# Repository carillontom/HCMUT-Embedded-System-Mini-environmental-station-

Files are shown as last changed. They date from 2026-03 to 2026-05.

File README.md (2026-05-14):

Group 8's project: Mini environmental station with STM32

Project Overview : Mini environmental monitoring station with module LCD display using I2C module and can alert with buzzer when certain conditions are met, sent data measured to phone UART app via Bluetooth with UART communication (module HC-05). The station use mcu stm32f103c8t6 aka blue pill that can measure real-time temperature & humidity (module DHT11), gas (module MQ2), and can display them on the lcd screen. The device also has 2 button, 1 to snooze the alarm, 1 to change the display mode in cycle.

Requirement definition: [https://docs.google.com/spreadsheets/d/1O582D53Wys3Cwzh6xRYdXv68gtSpY5OcIZm6p9dKSyE/edit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](https://docs.google.com/spreadsheets/d/1O582D53Wys3Cwzh6xRYdXv68gtSpY5OcIZm6p9dKSyE/edit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)

System specification: [https://docs.google.com/spreadsheets/d/1O582D53Wys3Cwzh6xRYdXv68gtSpY5OcIZm6p9dKSyE/edit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](https://docs.google.com/spreadsheets/d/1O582D53Wys3Cwzh6xRYdXv68gtSpY5OcIZm6p9dKSyE/edit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)

Block diagram: 
(In .pdf file)

Power tree:
(In .pdf file)

Schematic: 
(In .pdf file)

PCB Layout: 
(In .pdf file)

Full test: https://youtu.be/GwvQwB3FSAY
Gas test: https://youtu.be/L1KeKjgLLEk
Temp test: https://youtu.be/eYzAX3KRrvM

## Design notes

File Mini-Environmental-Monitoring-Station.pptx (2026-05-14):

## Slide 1

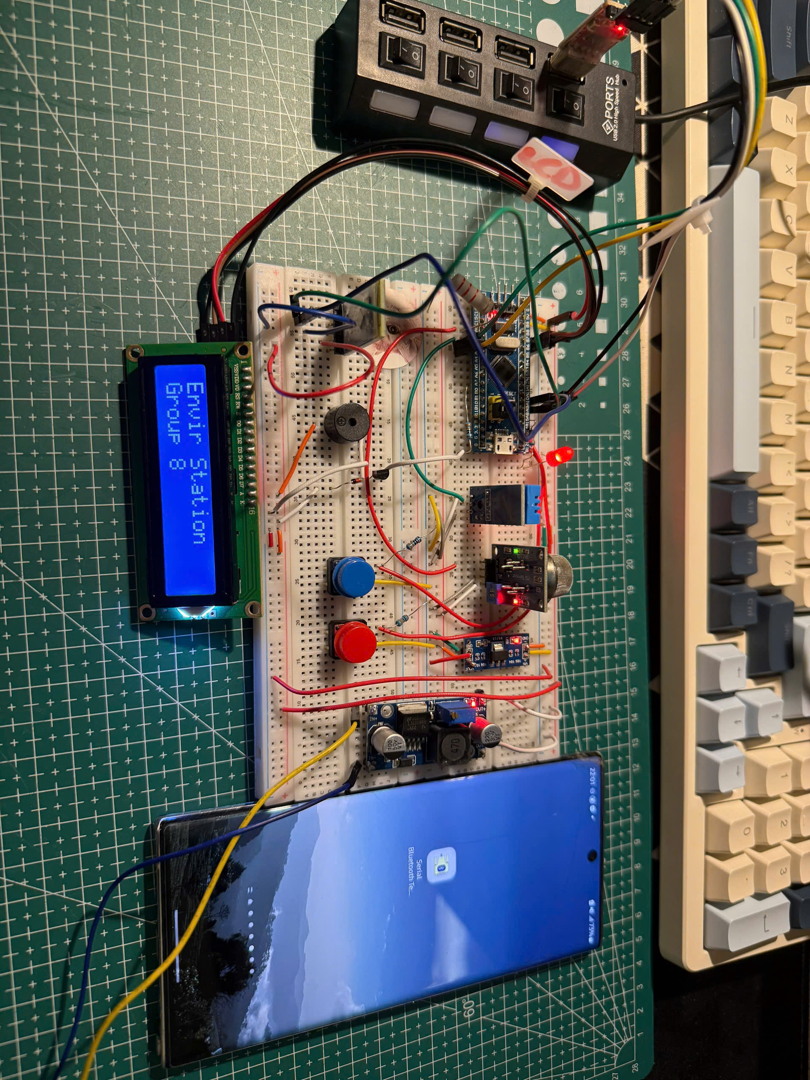
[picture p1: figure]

Mini Environmental Monitoring Station

Embedded System Design — Final Project Presentation

Instructor: MSc. Bui Quoc Bao

Name | ID
Pham Thanh Vinh | 2351075
Pham Hong An | 2310188
Ho Chi Dung | 2351016

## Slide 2

Presentation Contents

01

Project Overview

02

System Requirements

03

System Architecture & Hardware

04

Firmware Architecture

05

Integration & Testing

06

Demo

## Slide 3

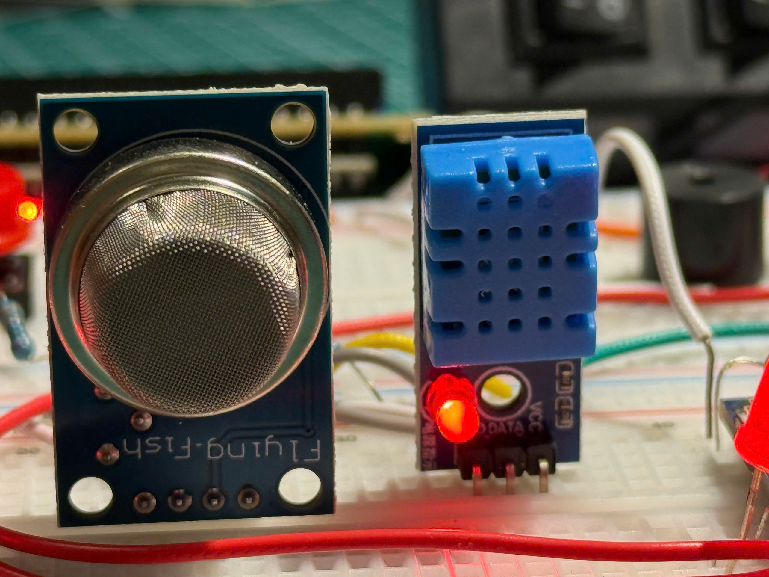
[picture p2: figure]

Project Overview

Sensors

Measure temperature, humidity, and gas/smoke concentration

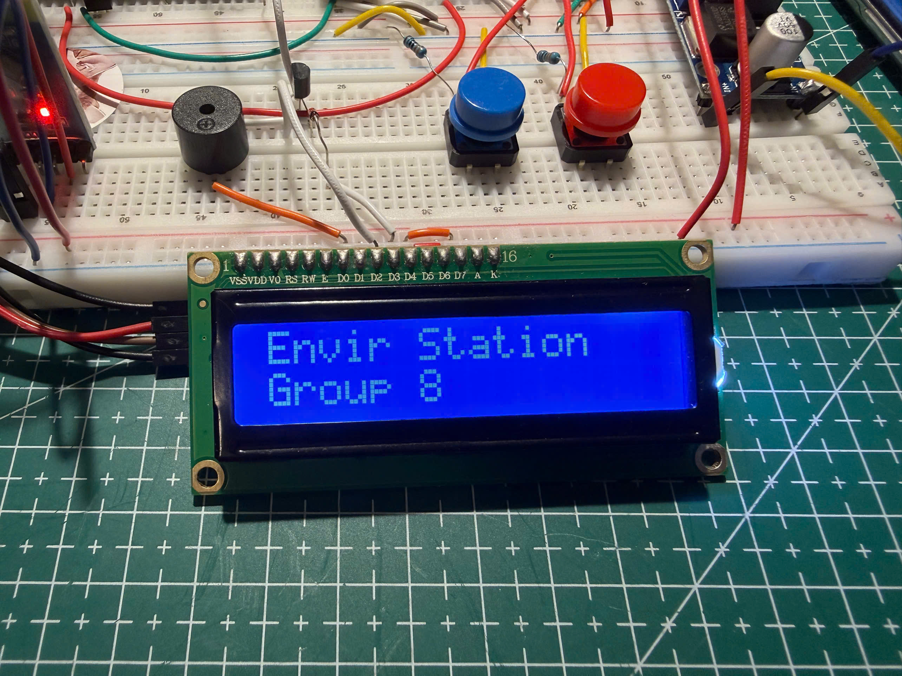
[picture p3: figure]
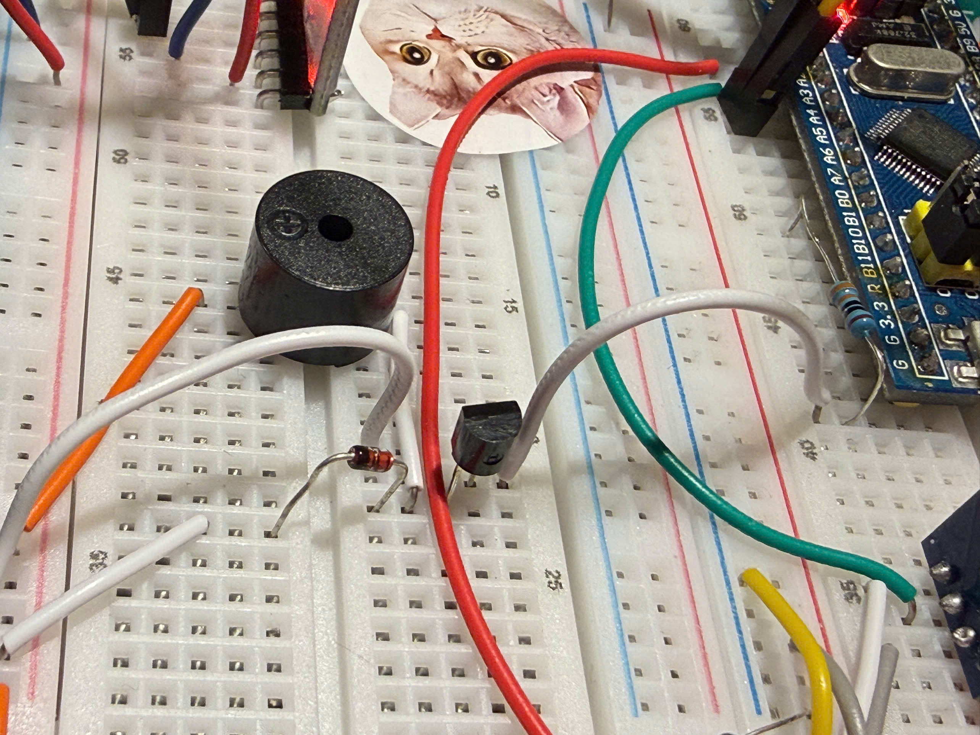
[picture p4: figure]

Show environmental information on a 16x2 LCD

Display

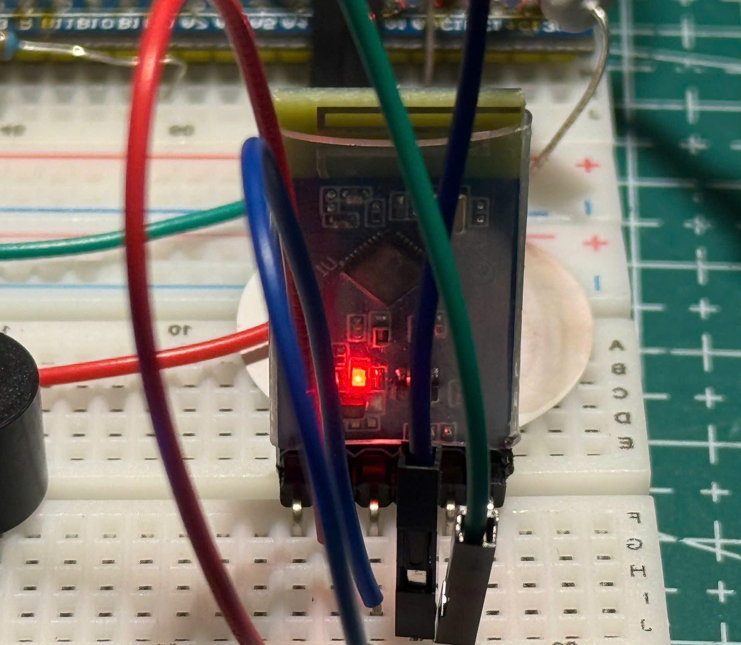
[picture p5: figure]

Activate the buzzer when gas concentration exceeds the threshold

Alert

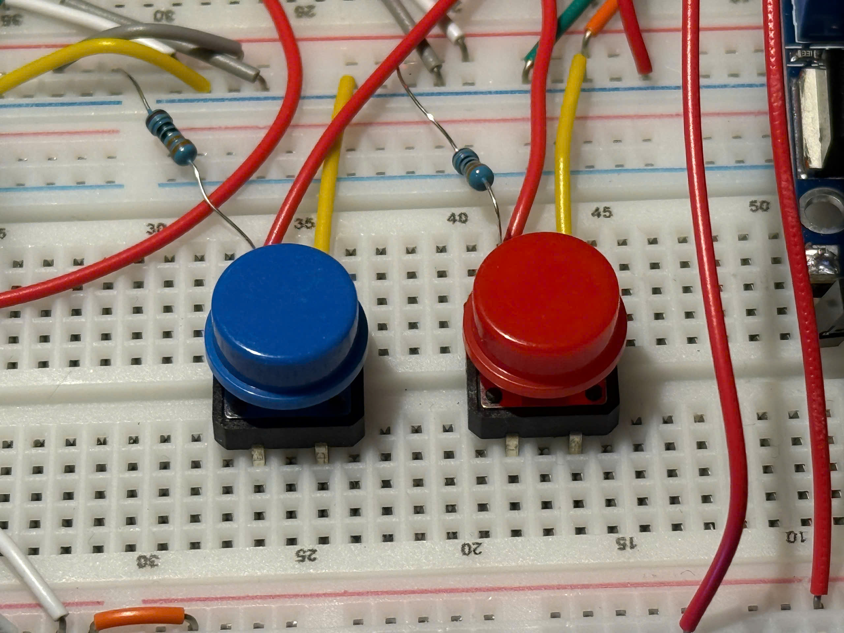
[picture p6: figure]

Transmit data to a smartphone via Bluetooth module

Wireless transmission

Complete the full embedded workflow from design to testing, with 2 user interaction buttons.

User interface

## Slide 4

System Requirements

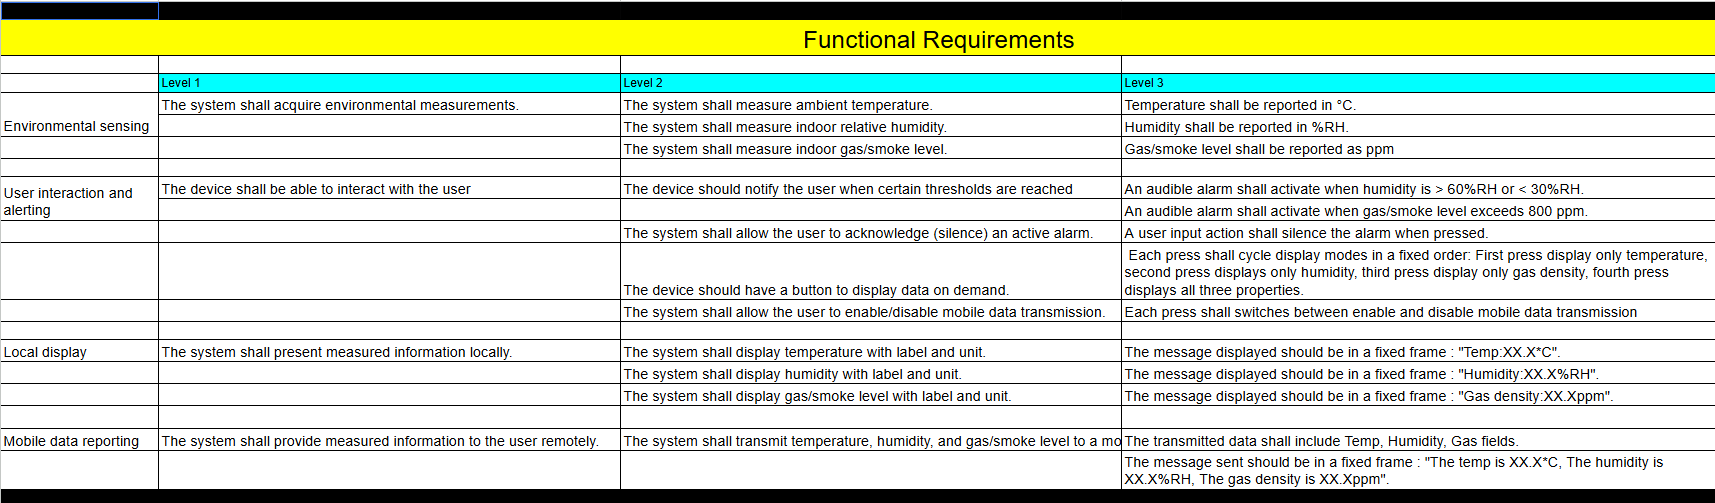
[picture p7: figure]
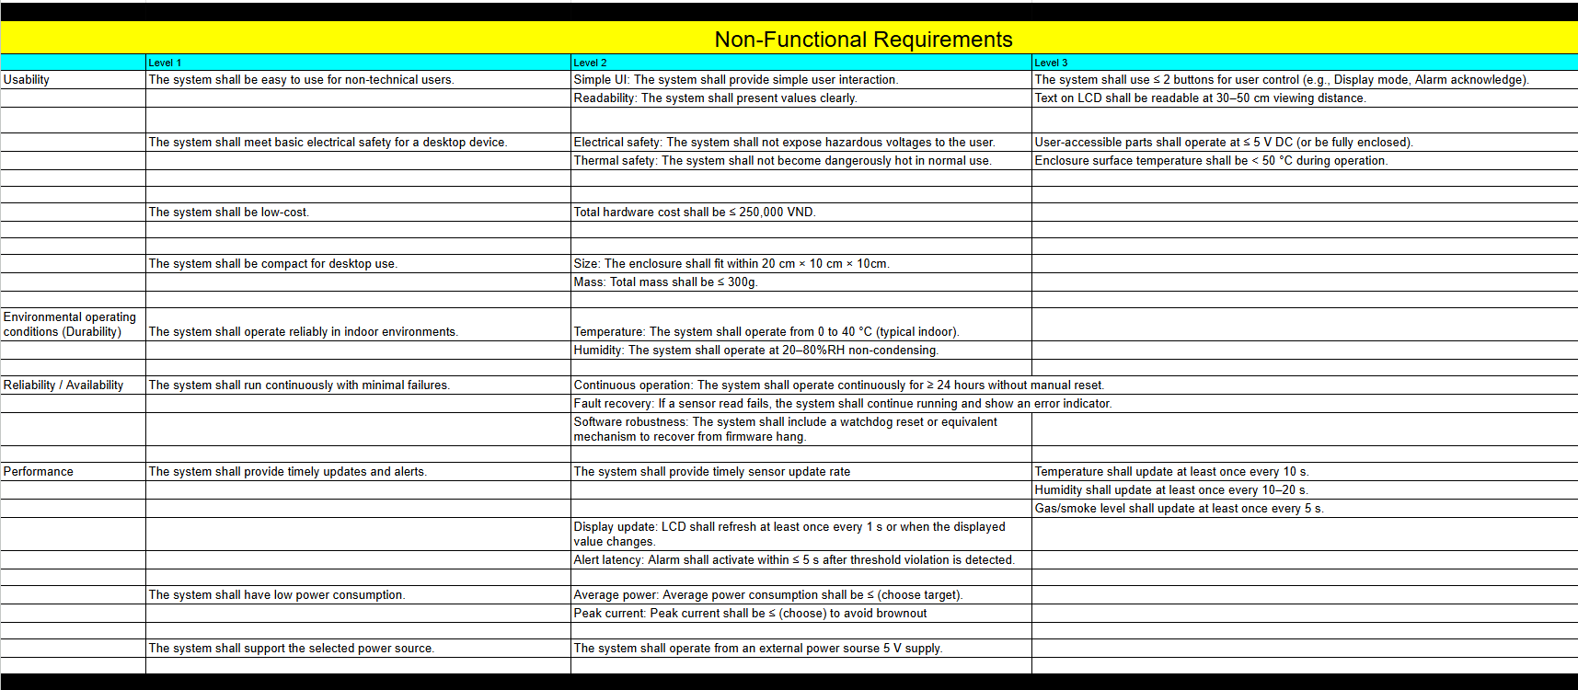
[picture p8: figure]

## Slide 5

Functional Requirements

- Measure temperature in °C.
- Measure humidity in %RH.
- Measure gas density in approximate ppm.
- Display values locally on LCD.
- Send environmental data wirelessly to phone.
- Activate buzzer when gas density exceeds threshold.
- BUTTON_1 changes gas threshold between 660 ppm and 10 ppm.
- BUTTON_2 cycles LCD display mode.

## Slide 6

Non - Functional Requirements

- Low-cost and compact desktop device.
- Easy to use with only 2 buttons.
- Stable 5V / 3.3V power distribution.
- Readable LCD output.
- Continuous operation for normal indoor monitoring.
- Modular code structure for easy debugging and extension.
- Real-time update and quick alarm response.

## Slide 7

System Architecture

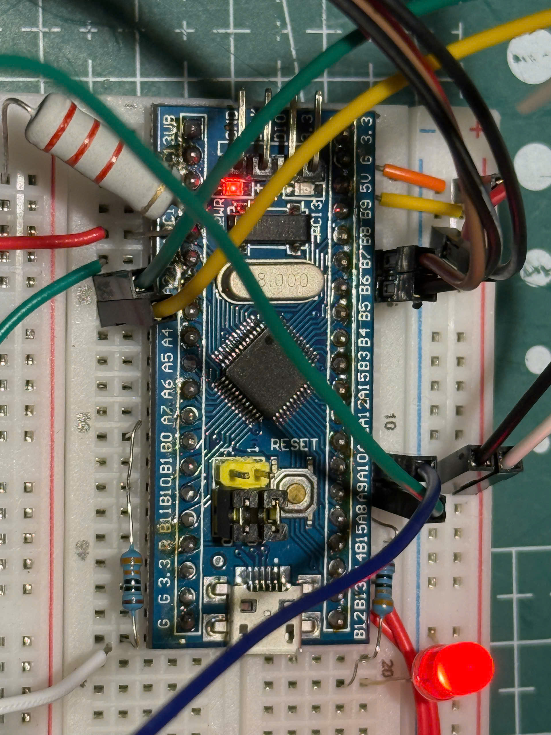
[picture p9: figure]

- Central controller: STM32F103C8T6.

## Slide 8

System Architecture

- Input blocks: MQ2, DHT11, Button 1, Button 2.

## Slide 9

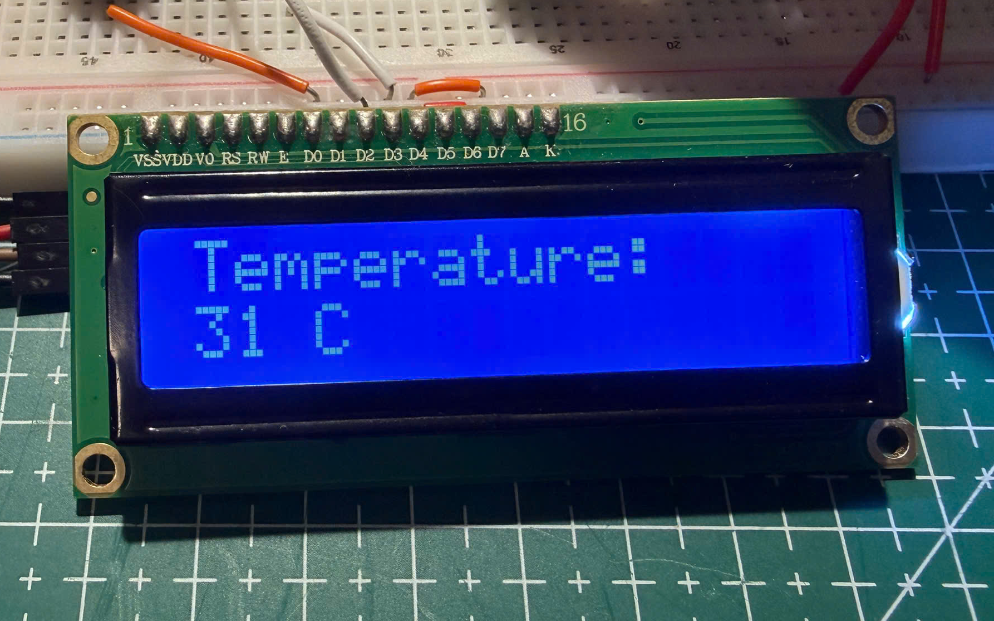
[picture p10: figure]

System Architecture

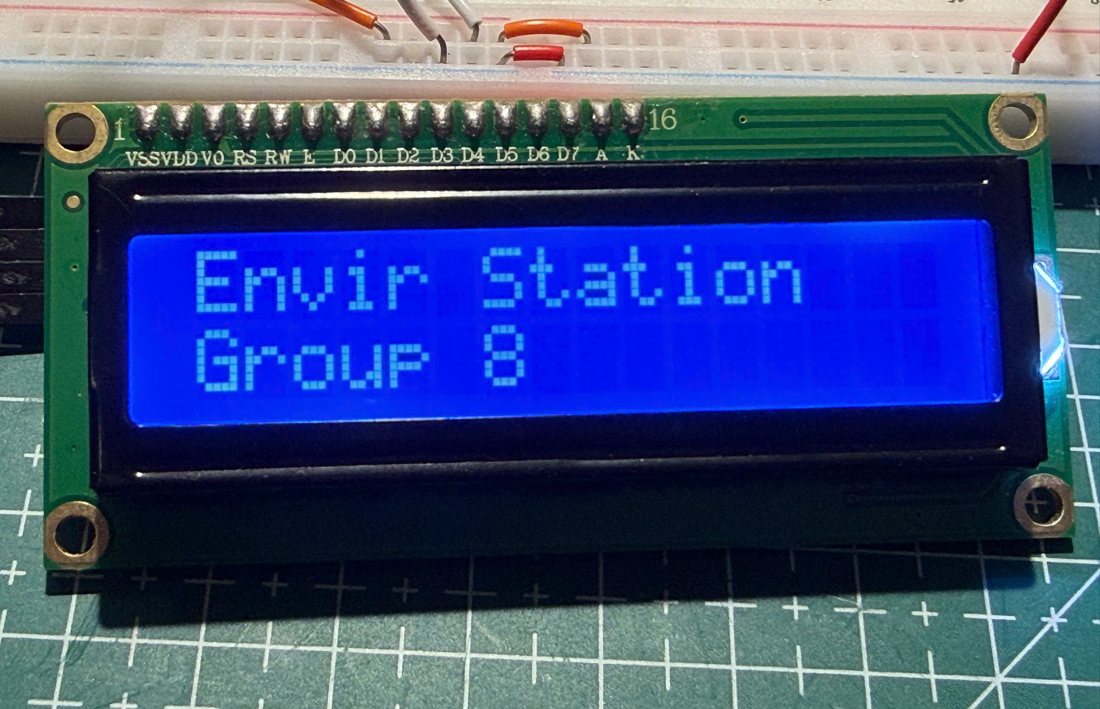
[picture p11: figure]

- Output blocks: LCD, Buzzer, LED, Bluetooth module.

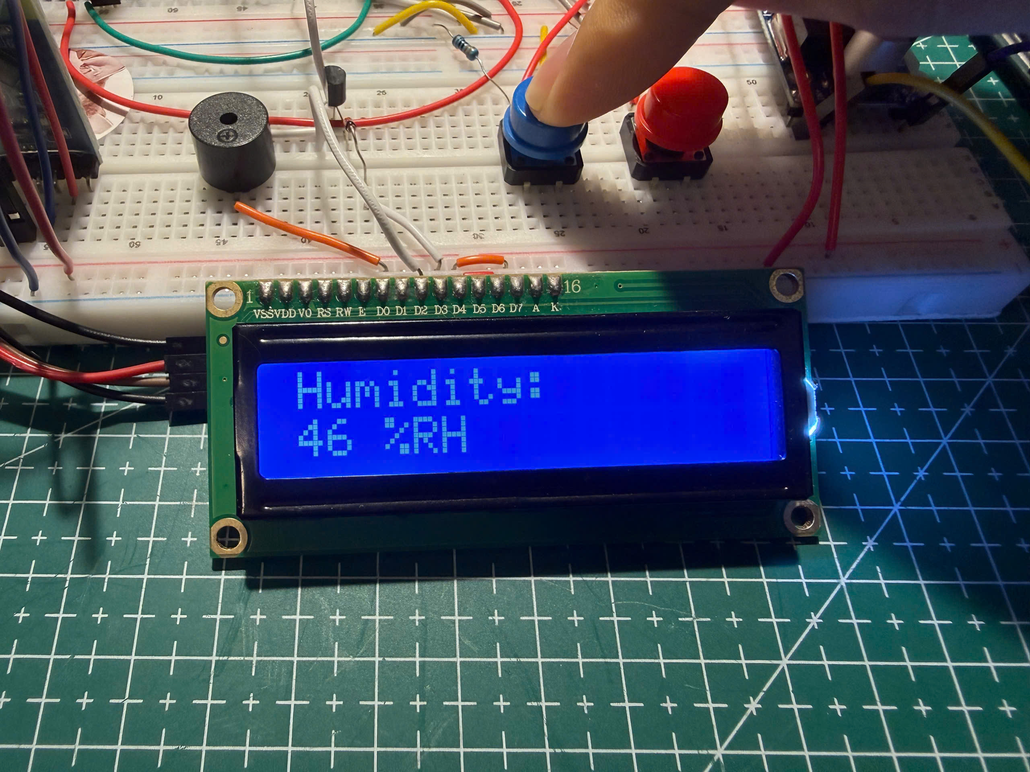
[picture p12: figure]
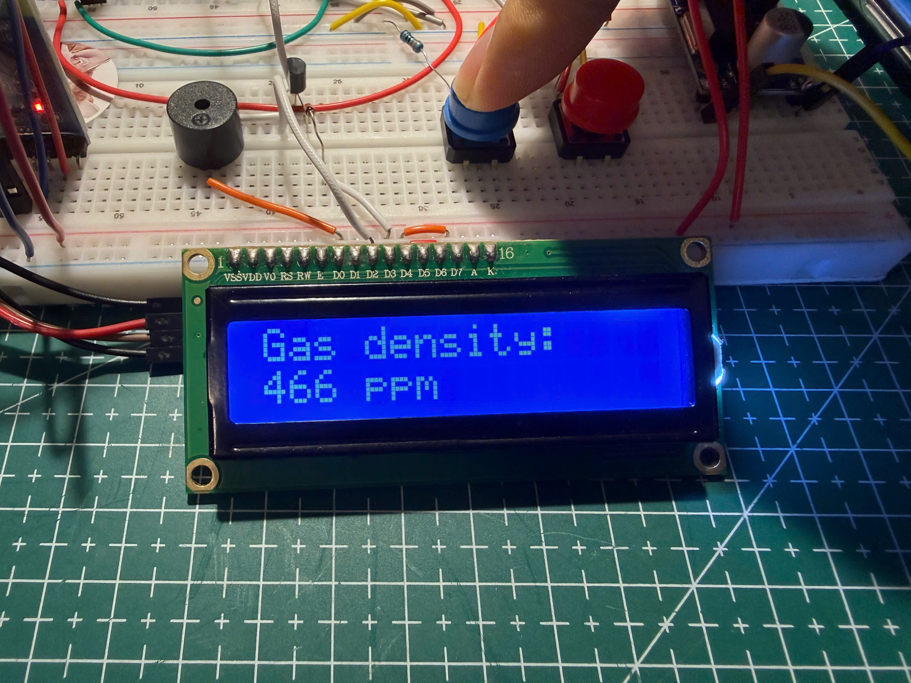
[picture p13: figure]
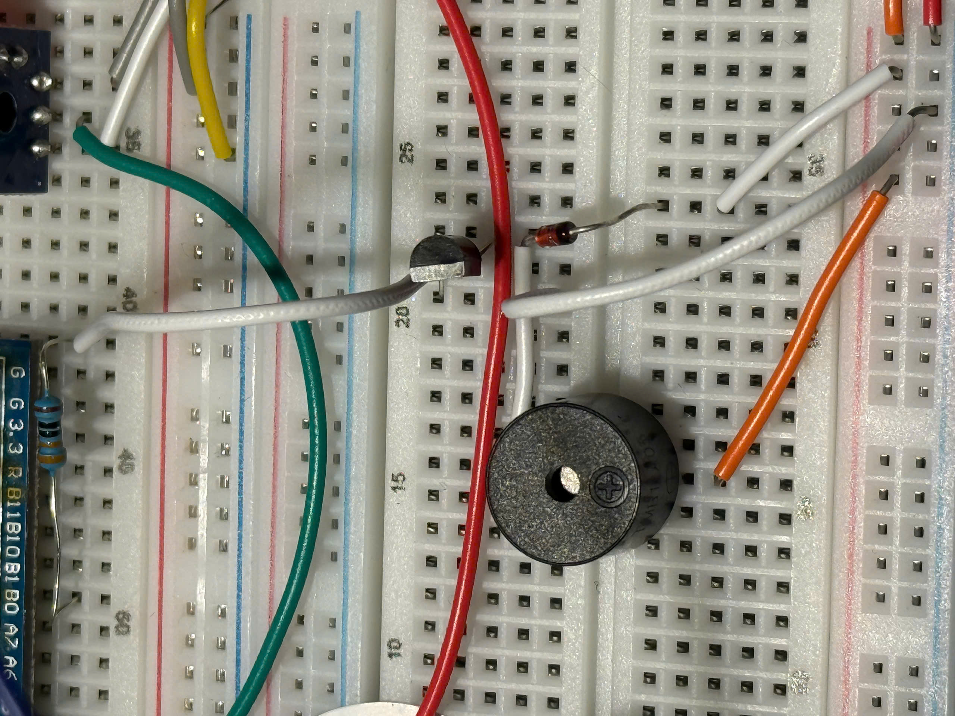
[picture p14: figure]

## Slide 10

System Architecture

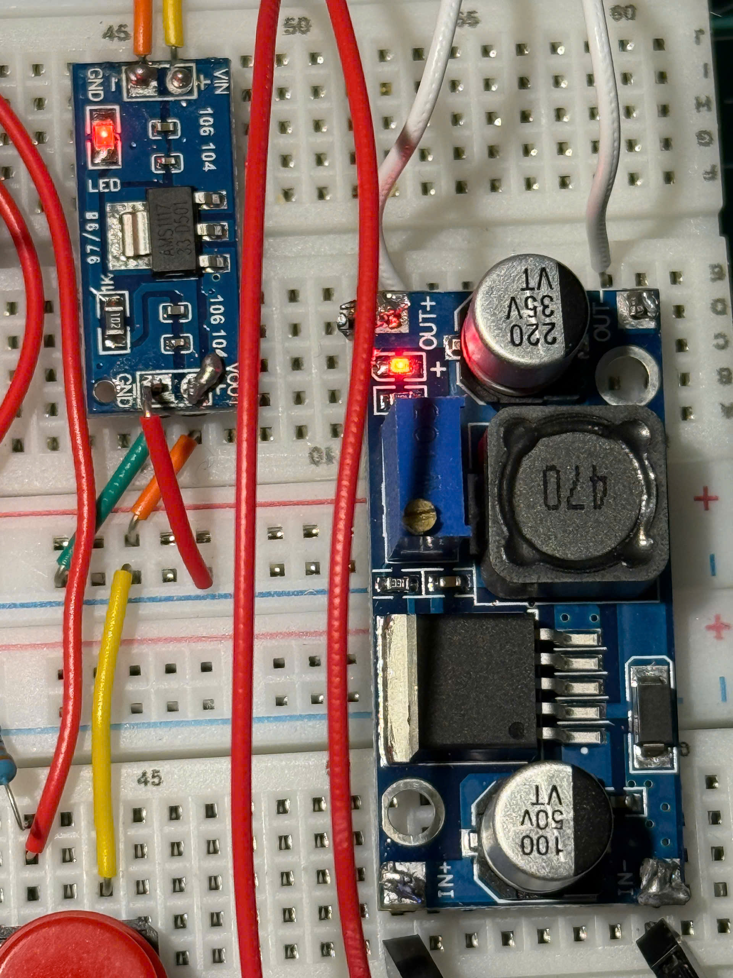
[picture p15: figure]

- Power subsystem: 9V input, LM2596 to 5V, AMS1117 to 3.3V.

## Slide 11

Block diagram

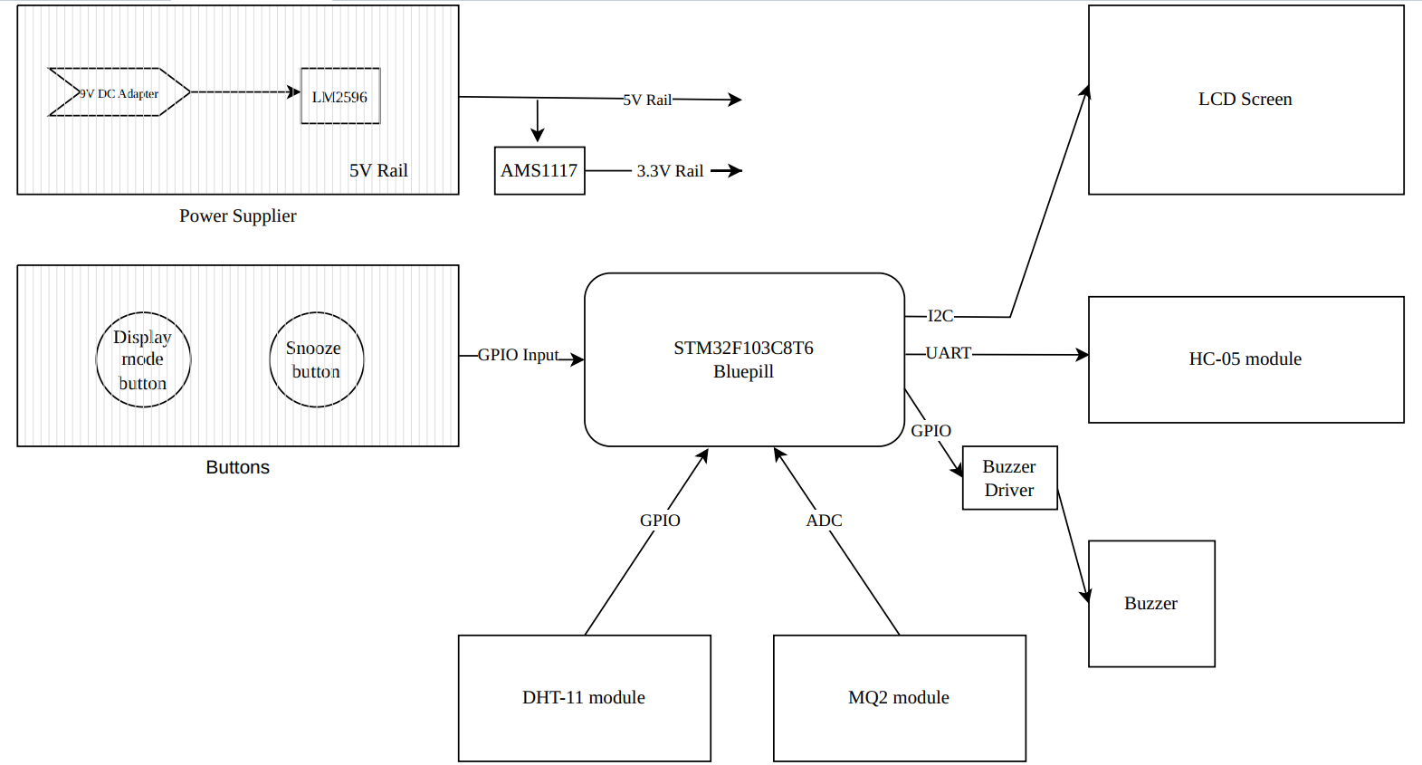
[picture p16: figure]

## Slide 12

Power tree

- 9V adapter as input source.
- LM2596 generates 5V rail.
- AMS1117 generates 3.3V rail.
- 5V powers LCD, gas sensor module, buzzer module, Bluetooth module.
- 3.3V powers MCU and logic-level blocks.

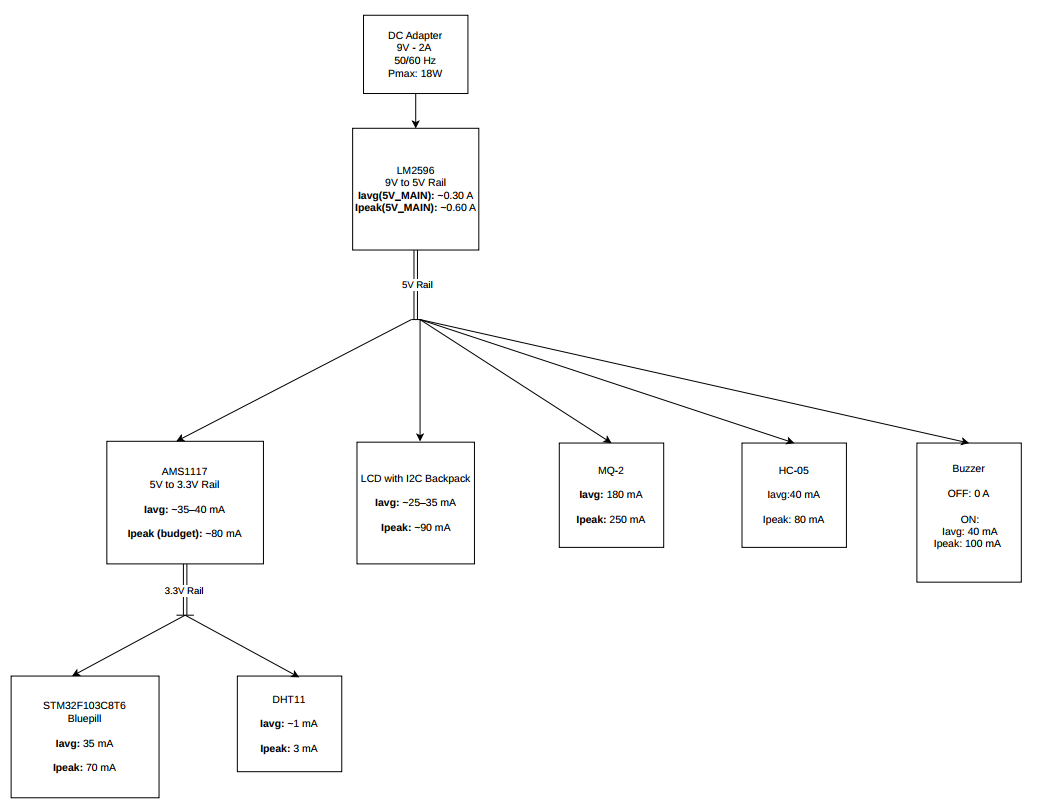
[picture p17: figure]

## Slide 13

Main schematic – Power supply

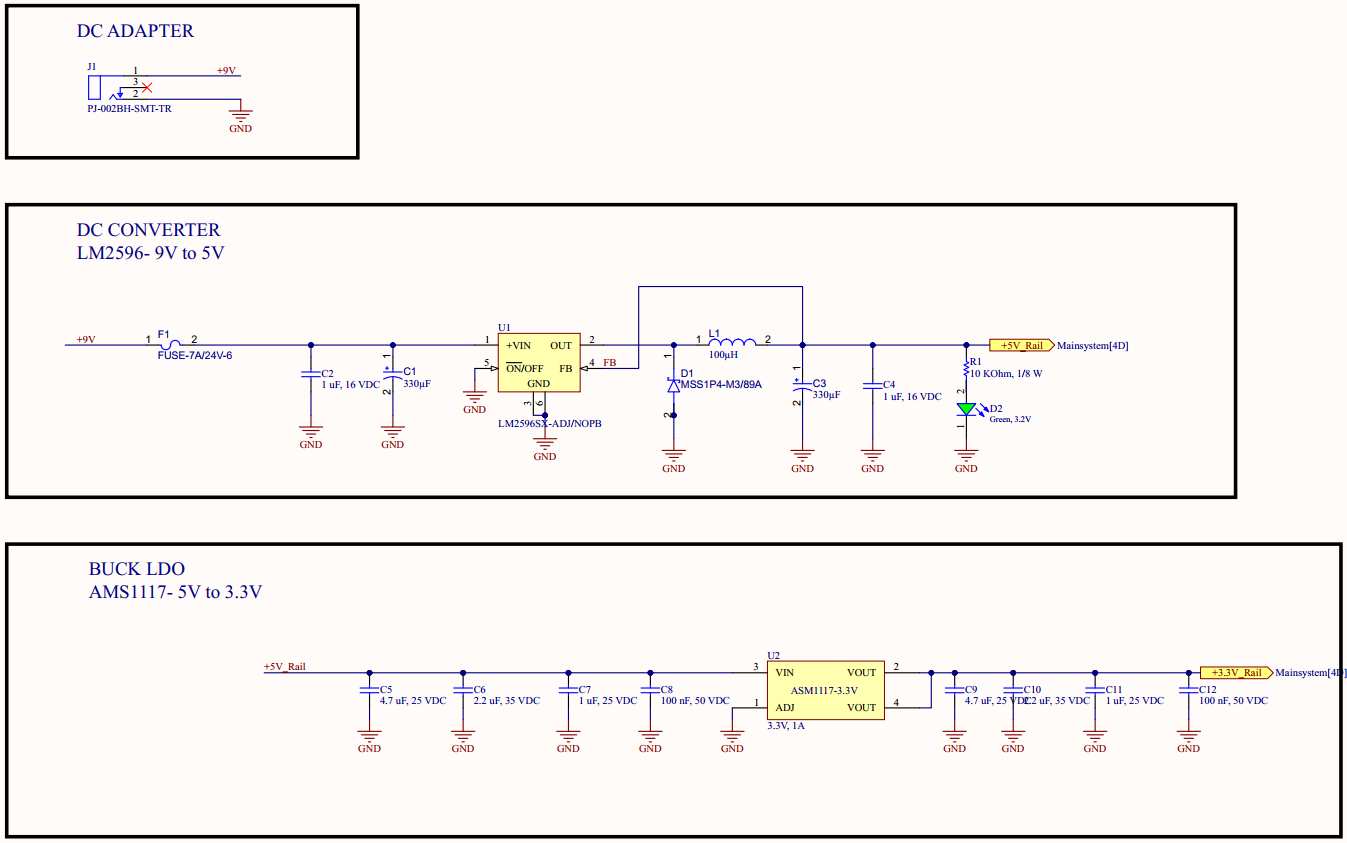
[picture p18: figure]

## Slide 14

Main schematic – Main system

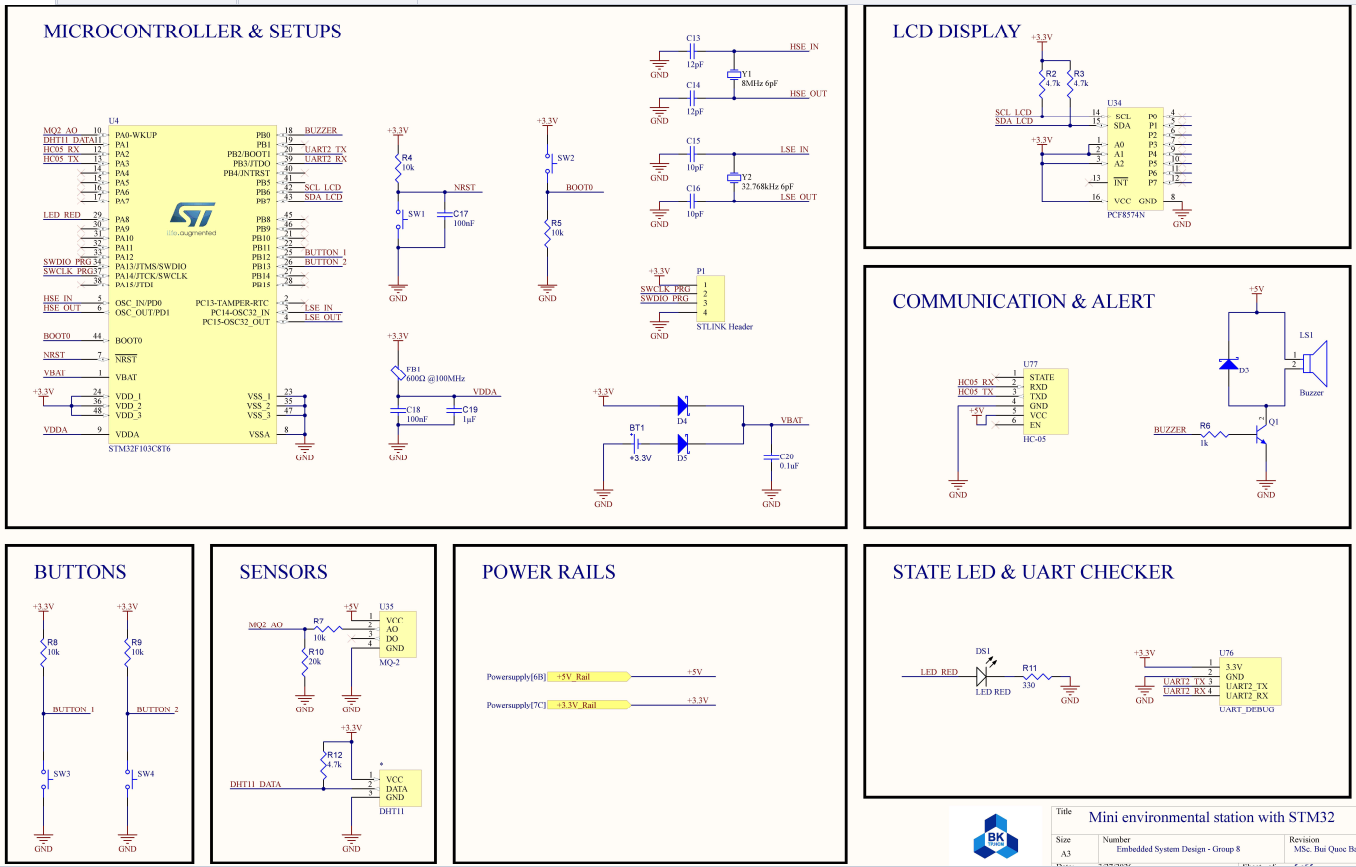
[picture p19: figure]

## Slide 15

PCB Layout

·PCB designed in Altium.
·2D layout and 3D render completed.
·Fabricated PCB successfully received.
·Breadboard was still used for fast debugging and subsystem validation before final full deployment.

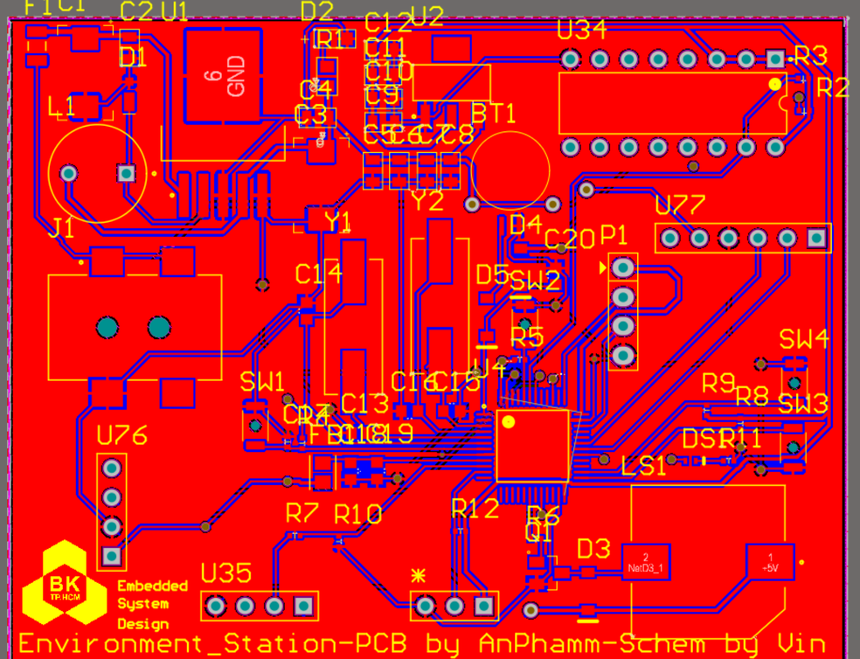
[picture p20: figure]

2D View

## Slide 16

PCB Layout

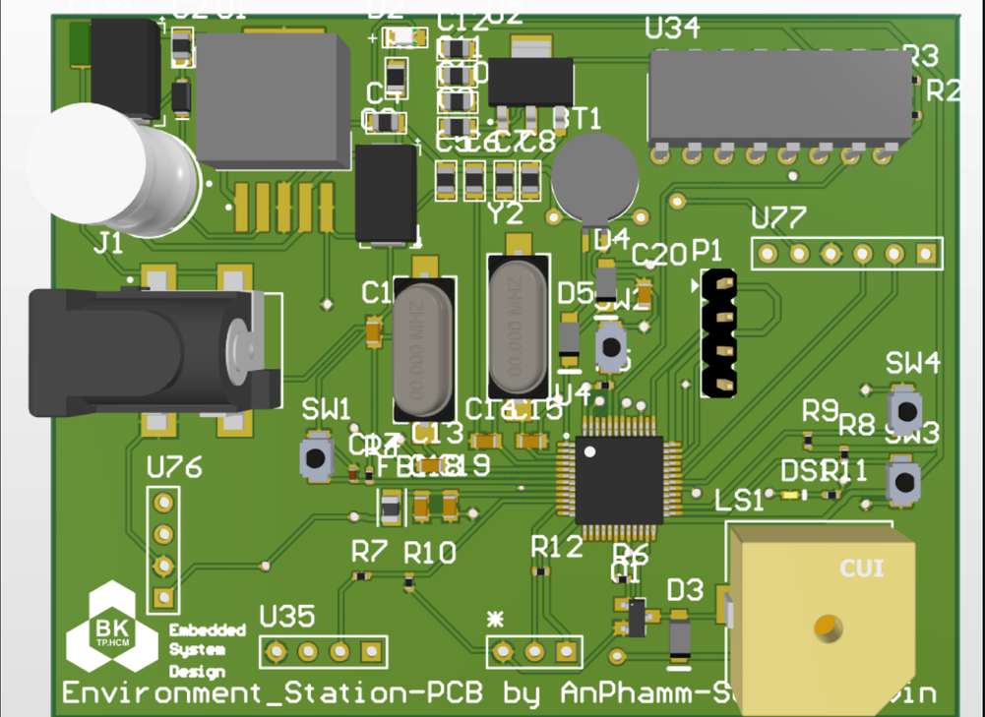
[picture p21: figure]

3D View

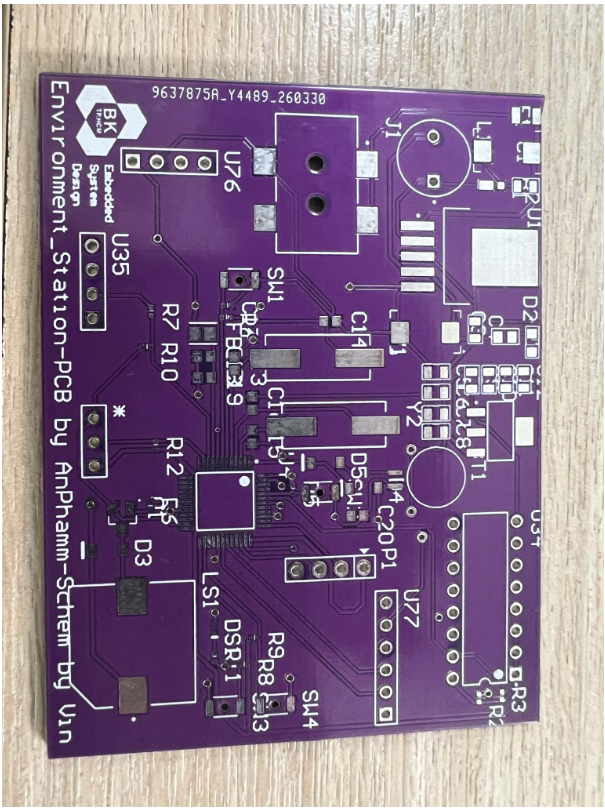
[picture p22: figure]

Printed PCB

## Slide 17

Firmware Architecture

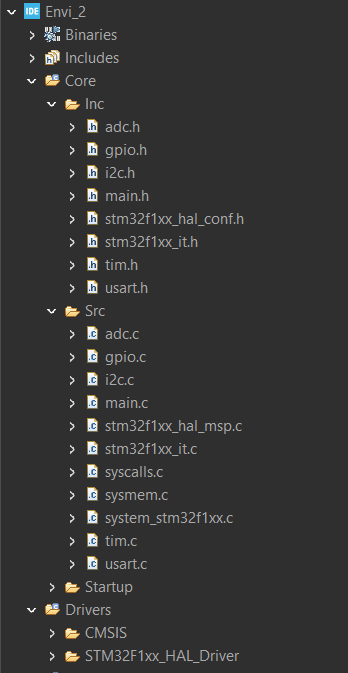
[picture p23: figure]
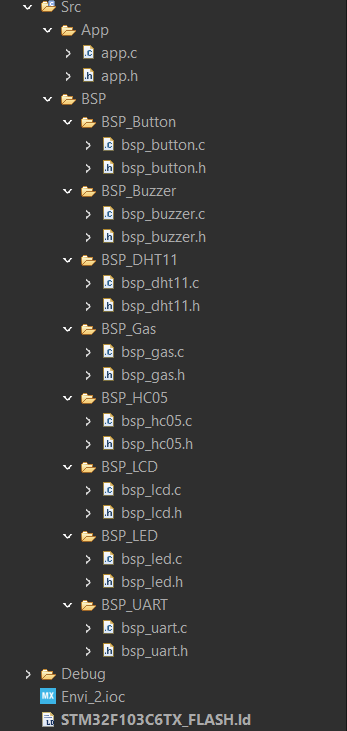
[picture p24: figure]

·Firmware organized into two layers: BSP layer and APP layer.
·BSP contains low-level drivers for each hardware block.
·APP contains the main system logic.
·Benefits: modularity, easier debugging, easier future extension

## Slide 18

Integration, Testing & Results

Full test: https://youtu.be/GwvQwB3FSAY
Gas test: https://youtu.be/L1KeKjgLLEk
Temp test: https://youtu.be/eYzAX3KRrvM

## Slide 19

Thank you

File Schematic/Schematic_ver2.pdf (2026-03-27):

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
Title

Size | Number | Revision
A3
Date: | 3/27/2026 | Sheet of
File: | C:\Users\..\Coverpage.SchDoc | Drawn By:

# COVER PAGE

Pham Thanh Vinh

Embedded System Design - Group 8 | MSc. Bui Quoc Bao

# Mini environmental station with STM32

### 1 of 5

# Mini environmental station with STM32

# Page .no Content

1
2
3
4
5

# Cover page Block diagram Power tree Power supply system Main system

CONTEXT | CONTEXT | CONTEXT

# BLOCK DIAGRAM


D D

C C

B B

A A

Title

File: | C:\Users\..\Block_diagram_page.SchDoc | Drawn By:

# Mini environmental station with STM32

### 2 of 5

# POWER TREE

# LM2596 Thermal Check


D D

C C

B B

A A

Title

File: | C:\Users\..\Power_tree_page.SchDoc | Drawn By:

Thanh Vinh & Hong An

# Mini environmental station with STM32

### 3 of 5

# AMS1117 Thermal Check

# POWER SUPPLY

# DC ADAPTER


Title
Mini environmental station with STM32

# MAIN SYSTEM

MICROCONTROLLER & SETUPS | LCD DISPLAY


D D

C C

B B

A A

Title

File: | C:\Users\..\Mainsystem.SchDoc | Drawn By:

BOOT0 44

NRST 7

OSC_IN/PD0 5
OSC_OUT/PD1 6

PA0-WKUP 10
PA1 11
PA2 12
PA3 13
PA4 14
PA5 15
PA6 16
PA7 17

PA8 29
PA9 30
PA10 31
PA11 32
PA12 33
PA13/JTMS/SWDIO 34
PA14/JTCK/SWCLK 37
PA15/JTDI 38
PB0 | 18
PB1 | 19
PB2/BOOT1 | 20
PB3/JTDO | 39
PB4/JNTRST | 40
PB5 | 41
PB6 | 42
PB7 | 43
PB8 | 45
PB9 | 46
PB10 | 21
PB11 | 22
PB12 | 25
PB13 | 26
PB14 | 27
PB15 | 28
PC13-TAMPER-RTC | 2
PC14-OSC32_IN | 3
PC15-OSC32_OUT | 4

VBAT 1

VDD_1 24
VDD_2 36
VDD_3 48

VDDA 9

VSS_1 | 23
VSS_2 | 35
VSS_3 | 47
VSSA | 8

U4

STM32F103C8T6
GND

VBAT

VDDA

SWDIO_PRG
SWCLK_PRG

NRST

HSE_IN
HSE_OUT | LSE_IN
| LSE_OUT

10k

R8

+3.3V

BUTTON_1

GND

10k

R9

+3.3V

BUTTON_2

GND

1k

R6

GND

1
2

LS1

Buzzer

BUZZER

GND

SCL_LCD
SDA_LCD

+3.3V

GND

4.7k

R12

DHT11_DATA

GND | GND

+3.3V

+3.3V

HC05_RX
HC05_TX

10k

MQ2_AO | R7

SCL_LCD
SDA_LCD

MQ2_AO
DHT11_DATA

BUZZER

BUTTON_1
BUTTON_2

BOOT0

FB1
600Ω @100MHz

10k

R4

+3.3V

NRST

100nF

C17

10k

R5

+3.3V

BOOT0

GND | GND

+3.3V

VDDA

1µF

C19

GND

GND

GND

HSE_IN

HSE_OUT

GND

GND

LSE_IN

LSE_OUT

1
2
3
4

P1

STLINK Header

SWCLK_PRG

+3.3V

GND

SWDIO_PRG

GND

VBAT

+3.3V

GND

# COMMUNICATION & ALERT

GND

BUTTONS | SENSORS

Powersupply[6B] +5V_Rail

Powersupply[7C] +3.3V_Rail

+5V

+3.3V

# POWER RAILS

# Mini environmental station with STM32

### 5 of 5

# STATE LED & UART CHECKER

DS1

LED RED

330

R11

GND | GND +3.3V

LED_RED
UART2_TX
UART2_RX

LED_RED

UART2_TX
UART2_RX

A0 1
A1 2
A2 3
P0 | 4
P1 | 5
P2 | 6
P3 | 7
GND | 8
P4 | 9
P5 | 10
P6 | 11
P7 | 12 INT 13

SCL 14
SDA 15

VCC 16

U34

PCF8574N

12pF

C13

12pF

C14

10pF

C15

10pF

C16

100nF

C18

0.1uF

C20

D3

D4
D5 | 2
Q1

4.7k

R2
4.7k

R3

20k

R10

SW1

SW2

SW3 | SW4

+3.3V

Y1
8MHz 6pF

Y2
32.768kHz 6pF

BT1

+3.3V

VCC 1
DATA 2
GND 3

*

DHT11

3.3V

1
GND

2
UART2_TX

3
UART2_RX

4

U76

UART_DEBUG

+5V

STATE 1
RXD 2
TXD 3
GND 4
VCC 5
EN 6

U77

HC-05

+5V

+5V
VCC 1
AO 2
DO 3
GND 4

U35

MQ-2

HC05_TX

HC05_RX

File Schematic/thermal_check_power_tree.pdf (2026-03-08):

## Thermal Check Report (Power Tree – Actual Load Budget)

System regulators: LM2596 (9V→5V) + AMS1117-3.3V (5V→3.3V)

### 1. Inputs from Power Tree

Ambient temperature cases: Ta = 25°C (typ) and 60°C (worst enclosed).
LM2596 efficiency assumption: η = 80–85% (depends on module/layout and load). Thermal resistance (θJA) estimates for quick check (PCB/module dependent):
- LM2596: 40–80 °C/W • AMS1117 (SOT-223): 50–100 °C/W

### 2. Load Summary

2.1 5V Rail Loads (from LM2596)

5V Load | Iavg (mA) | Ipeak (mA)
AMS1117 input (5V→3.3V) | 35–40 | 80 (budget)
LCD with I2C backpack | 25–35 | 90
MQ-2 gas sensor | 180 | 250
HC-05 Bluetooth | 40 | 80
Buzzer (ON) | 40 | 100

5V rail totals (actual budget):

- Iavg (Buzzer OFF): 280–295 mA ⇒ Pout = 1.40–1.48 W
- Iavg (Buzzer ON): 320–335 mA ⇒ Pout = 1.60–1.68 W
- Ipeak (sum peaks): 600 mA ⇒ Pout = 3.00 W

2.2 3.3V Rail Loads (from AMS1117-3.3V)

3.3V Load | Iavg (mA) | Ipeak (mA)
STM32F103C8T6 (Bluepill) | 35 | 70

DHT11 | 1 | 3

3.3V rail totals: Iavg ≈ 36 mA, Ipeak ≈ 73 mA (budgeted to 80 mA).

### 3. Thermal Check (Quick)

### 3.1 LM2596 (Buck) – 9V→5V

Formulas: Pout = 5V × Iout; Ploss ≈ Pout × (1/η − 1); ΔT ≈ Ploss × θJA; Tj ≈ Ta + ΔT

Case | Iout | Pout | Ploss (η=80– 85%) | ΔT est. (θJA 40–80) | Tj est. @ Ta=25/60
5V average (Buzzer OFF) | 280–295 mA | 1.40–1.47 W | 0.25–0.37 W | 10–30 °C | 25°C: 35– 55°C 60°C: 70– 90°C
5V average (Buzzer ON) | 320–335 mA | 1.60–1.68 W | 0.28–0.42 W | 11–34 °C | 25°C: 36– 59°C 60°C: 71– 94°C
5V peak (sum peaks) | 600 mA | 3.00 W | 0.53–0.75 W | 21–60 °C | 25°C: 46– 85°C 60°C: 81– 120°C

Notes: LM2596 temperature rise strongly depends on PCB copper/heatsinking and the module implementation. Verify with a prototype thermal measurement at worst-case load.

### 3.2 AMS1117-3.3V (LDO) – 5V→3.3V

Formula: Ploss = (Vin − Vout) × Iout = 1.7V × Iout

Case | Iout | Pout | Ploss | ΔT est. (θJA 50–100) | Tj est. @ Ta=25/60
Average (actual 3.3V loads) | 36 mA | 0.119 W | 0.061 W | 3–6 °C | 25°C: 28– 31°C 60°C: 63–

| | | | | 66°C
Peak (sum peaks on 3.3V) | 73 mA | 0.241 W | 0.124 W | 6–12 °C | 25°C: 31– 37°C 60°C: 66– 72°C
Budget (design margin) | 80 mA | 0.264 W | 0.136 W | 7–14 °C | 25°C: 32– 39°C 60°C: 67– 74°C

Conclusion: AMS1117 at ~36 mA average has very low thermal dissipation. The main thermal attention is on LM2596 (and the MQ-2 heater as a local heat source).

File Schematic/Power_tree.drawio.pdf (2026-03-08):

DC Adapter 9V - 2A 50/60 Hz Pmax: 18W; LM2596 9V to 5V Rail Iavg(5V_MAIN): ~0.30 A Ipeak(5V_MAIN): ~0.60 A; AMS1117 5V to 3.3V Rail; Iavg: ~35–40 mA; Ipeak (budget): ~80 mA; STM32F103C8T6 Bluepill; Iavg: 35 mA; Ipeak: 70 mA; DHT11; Iavg: ~1 mA; Ipeak: 3 mA; Iavg: 180 mA; Ipeak: 250 mA; LCD with I2C Backpack; Iavg: ~25–35 mA; Ipeak: ~90 mA; Iavg:40 mA; Ipeak: 80 mA; Buzzer; OFF: 0 A; ON: Iavg: 40 mA Ipeak: 100 mA; 5V Rail; 3.3V Rail

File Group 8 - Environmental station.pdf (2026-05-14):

## VIETNAM NATIONAL UNIVERSITY

## HO CHI MINH CITY UNIVERSITYOF TECHNOLOGY

## Embedded System

## Mini environmental station with STM32

## Instructor: MSc. Bùi Quốc Bảo

Student | Student ID
Phạm Thành Vinh | 2351075
Phạm Hồng Ân | 2310188
Hồ Chí Dũng | 2351016

Ho Chi Minh City – March 2026

## Division of work

No. | Full Name | Student ID | Task Description | Status | Signature
1 | Phạm Thành Vinh | 2351075 | ❖ Requirements definition ❖ System specification ❖ Block diagram ❖ Power tree ❖ Main system schematic ❖ Firmware development and simulation ❖ Breadboard integration and debugging | 100%
2 | Phạm Hồng Ân | 2310188 | ❖ Requirements definition ❖ Power supply schematic ❖ Thermal check table ❖ PCB layout ❖ Presentation slides | 100%
3 | Hồ Chí Dũng | 2351016 | ❖ Report writing | 100%

## Table of Contents

## LIST OF FIGURES

Figure Number | Description
Figure 5.3.1 | Power supply modules LM2596 and AMS1117
Figure 5.3.2 | Power Distribution Tree (Full schematic page)
Figure 5.3.3 | Power Distribution Tree (Zoom in)
Figure 5.3.4 | Power Supply Schematic (Full schematic page)
Figure 5.3.5 | Power Supply Schematic (Zoom in)
Figure 5.4.1 | DHT-11 Sensor
Figure 5.4.2 | MQ-2 Sensor
Figure 5.5.1 | LCD Screen with I2C backpack PCF8574
Figure 5.5.2 | Buttons and their drivers
Figure 5.5.3 | Buzzer and its drivers
Figure 5.5.4 | Bluetooth module
Figure 5.6.1 | Overall System Schematic (Full schematic page)
Figure 5.6.2 | Overall System Schematic (Zoom in)
Figure 5.7.1 | 2D PCB Layout
Figure 5.7.2 | 3D PCB Render
Figure 5.8.1 | Fabricated PCB - Top Side
Figure 5.8.2 | Fabricated PCB - Bottom Side
Figure 6.1 | Firmware structure
Figure 7.1 | Full system integration on breadboard
Figure 7.2.1 | The simulation model in Proteus
Figure 7.2.2 | Successful simulation result with buzzer on and HC-05 sending messages
Figure 7.3.1 | LCD displaying gas density mode
Figure 7.3.2 | LCD displaying temperature mode
Figure 7.3.3 | LCD displaying humidity mode
Figure 7.3.4 | Phone app successfully received messages from Bluetooth module HC-05
Figure 7.3.5 | Hercules successfully received messages from USB-to-TTL module
Figure 7.3.6 | Gas density in normal condition
Figure 7.3.7 | Gas density in smoke environment
Figure 7.3.8 | Temperature in normal condition
Figure 7.3.9 | Temperature near a soldering iron

## 1. Introduction

With the rapid growth of urbanization and industrialization, monitoring environmental indicators such as temperature, humidity, and gas concentration has become essential for public health and fire safety. Maintaining optimal indoor air quality is a critical necessity for preventing respiratory issues and ensuring early fire detection in residential and office spaces. Traditional monitoring systems are often bulky and expensive, making them impractical for small-scale applications. Embedded systems, particularly those powered by the STM32F103C8T6 microcontroller, offer a dedicated, low-power solution for real-time sensing and processing. By utilizing this technology, it is possible to create a compact device that handles high-speed sensor data without the complexity or cost of a general-purpose computer.

Manual environmental tracking is often inconsistent and fails to provide the immediate warnings necessary during critical events, such as gas leaks or extreme humidity fluctuations. Current consumer-grade devices frequently lack a cohesive balance between affordability and accessibility, often providing either only a local display or only a remote connection. This project addresses the need for a compact, low-cost yet highly reliable embedded system that bridges this gap. The core problem solved is the lack of a unified desktop station that offers dual-monitoring capability: local feedback for immediate checks and remote tracking for convenience. Furthermore, the system must overcome the limitations of passive monitoring by integrating active audible alerts for abnormal conditions.

The primary objective of this project is to develop a "Mini Environmental Monitoring Station" that serves as a comprehensive practice of embedded system design. The technical goals include integrating various sensors for real-time measurement, specifically the DHT11 for temperature and humidity and the MQ2 for gas and smoke detection. The station aims to implement local data visualization via an I2C LCD and remote tracking through a Bluetooth (HC-05) connection to a mobile application. Additionally, the project requires the design of an integrated buzzer alarm to provide immediate alerts for hazardous environmental conditions. Beyond software logic, the objective is to complete a full hardware development cycle, encompassing peripheral communication protocols such as I2C, UART, and ADC from schematic design to PCB fabrication.

The scope of this project is limited to an indoor desktop monitoring station designed for residential or office environments. While the system integrates multiple professional communication protocols, it is important to note certain technical limitations. The MQ2 sensor is a low-cost module and is not intended for industrial-grade ppm accuracy; it serves as a relative indicator for safety thresholds. Similarly, the DHT11 sensor provides humidity and temperature readings suitable for consumer use but has a lower sampling rate and accuracy range compared to laboratory-grade equipment. This project focuses on the implementation of a functional embedded prototype rather than a final commercial product.

This report is organized to follow the standard engineering design process. Chapter 2 defines the functional and non-functional requirements that the system must satisfy. Chapter 3 provides the detailed technical specifications for the hardware and software subsystems. Chapter 4 describes the system partitioning and the overall architecture, including the core block diagrams. Chapter 5 details the hardware design, covering the power tree, schematics, and PCB layout. Chapter 6 explains the firmware workflow and logic implementation. Chapter 7 presents the integration process and the results of the final system testing. Finally, Chapter 8 concludes the project and outlines potential future improvements.

In the final implementation, the gas density value shown in ppm is a scaled approximate value used for demonstration and threshold-based safety indication rather than an industrially calibrated gas concentration measurement.

## 2. System Requirements

## 2.1. Functional Requirements

### 1. Environmental sensing

FR-1.1 The system shall acquire environmental measurements.

FR-1.1.1 The system shall measure ambient temperature. Temperature shall be reported in °C.

FR-1.1.2 The system shall measure indoor relative humidity. Humidity shall be reported in %RH.

FR-1.1.3 The system shall measure indoor gas/smoke level. Gas/smoke level shall be reported as ppm.

### 2. User interaction and alerting

FR-2.1 The device shall provide user interaction through two push buttons.

FR-2.1.1 BUTTON_1 shall switch the gas alarm threshold between two preset values for demonstration: 660 ppm and 10 ppm.

FR-2.1.2 BUTTON_2 shall cycle the LCD display mode through four fixed screens.

FR-2.1.3 The four LCD modes shall be: (1) welcome screen, (2) gas density, (3) temperature, and (4) humidity.

### 3. Local display

FR-3.1 The system shall present measured information locally on a 16x2 LCD.

FR-3.1.1 Mode 1 shall display a welcome screen with line 1 “Envir Station” and line 2 “Group 8”.

FR-3.1.2 Mode 2 shall display gas density with label and unit in ppm.

FR-3.1.3 Mode 3 shall display temperature with label and unit in degree Celsius.

FR-3.1.4 Mode 4 shall display humidity with label and unit in percentage relative humidity.

### 4. Mobile data reporting

FR-4.1 The system shall transmit environmental information wirelessly through the HC-05 Bluetooth UART module.

FR-4.1.1 The transmitted data shall include temperature, humidity, and gas density.

FR-4.1.2 The firmware shall send three separate fixed-format messages: “Temp:XX.0*C”, “Humidity:XX.0%RH”, and “Gas density:XXX ppm”, followed by a separator line.

## 2.2. Non-Functional Requirements

### 1. Usability

NFR-1.1. The system shall be easy to use for non-technical users.

NFR-1.1.1. Simple UI: The system shall provide simple user interaction. The system shall use less than or equal to 2 buttons for user control (e.g., Display mode, Alarm acknowledge).

NFR-1.2. Readability: The system shall present values clearly.

NFR-1.2.1. Text on LCD shall be readable at 30-50 cm viewing distance.

NFR-1.3. The system shall meet basic electrical safety for a desktop device.

NFR-1.3.1. Electrical safety: The system shall not expose hazardous voltages to the user. User-accessible parts shall operate at less than or equal to 5 V DC (or be fully enclosed).

NFR-1.4. Thermal safety: The system shall not become dangerously hot in normal use.

NFR-1.4.1. Enclosure surface temperature shall be less than 50 degrees C during operation.

NFR-1.5. The system shall be low-cost.

NFR-1.5.1. Total hardware cost shall be less than or equal to 250,000 VND.

NFR-1.6. The system shall be compact for desktop use.

NFR-1.6.1. Size: The enclosure shall fit within 20 cm x 10 cm x 10 cm. Mass: Total mass shall be less than or equal to 300g.

### 2. Durability

NFR-2.1. The system shall operate reliably in indoor environments.

NFR-2.1.1. Temperature: The system shall operate from 0 to 40 degrees C (typical indoor). Humidity: The system shall operate at 20-80%RH non-condensing.

### 3. Reliability

NFR-3.1. The system shall run continuously with minimal failures.

NFR-3.1.1. Continuous operation: The system shall operate continuously for greater than or equal to 24 hours without manual reset.

NFR-3.2. Fault recovery: If a sensor read fails, the system shall continue running and show an error indicator.

NFR-3.2.1 Software robustness: If a sensor read fails, the firmware shall continue running, preserve the remaining system functions, and report the fault through the debug interface.

### 4. Performance

NFR-4.1. The system shall provide timely updates and alerts.

NFR-4.1.1. The system shall provide timely sensor update rate.

NFR-4.1.2. Temperature shall update at least once every 10 s. Humidity shall update at least once every 10-20 s. Gas/smoke level shall update at least once every 5 s.

NFR-4.2. Display update: LCD shall refresh at least once every 1 s or when the displayed value changes.

NFR-4.2.1. Alert latency: Alarm shall activate within less than or equal to 5 s after threshold violation is detected.

NFR-4.3. The system shall have low power consumption.

NFR-4.3.1. Average power: Average power consumption shall be less than or equal to .Peak current: Peak current shall be less than or equal to, to avoid brownout.

NFR-4.4. The system shall support the selected power source.

NFR-4.4.1. The system shall operate from an external power source 5 V supply.

## 2.3. Requirement validation

The requirement validation process ensures that the final report reflects the implemented

prototype rather than an idealized design. Each requirement is checked against either simulation

results, breadboard measurements, wireless terminal outputs, or LCD observations. The final

prototype demonstrates successful integration of sensing, display, alert, and wireless

transmission functions. In addition, the validation process confirms that the two-button user

interface behaves consistently with the implemented firmware: BUTTON_1 changes the gas

alarm threshold, and BUTTON_2 cycles the LCD display modes. Requirements that were not

fully demonstrated in Proteus, such as perfectly stable DHT11 behavior or exact calibrated gas

ppm, are discussed honestly as implementation limitations rather than overstated as fully

validated specifications.

## 3. System Specifications

## 3.1. Product Specification

The Mini Environmental Station is a compact desktop embedded device for indoor

environmental monitoring. The final prototype measures temperature and humidity using a

DHT11 sensor and estimates gas concentration using an MQ2 analog sensor. Data is shown

locally on a 16x2 I2C LCD and transmitted wirelessly through a HC-05 Bluetooth UART

module to a mobile serial terminal application. The system also includes an active buzzer for

gas-threshold warning and a heartbeat LED to indicate that the firmware is running normally.

Two push buttons are used for user interaction: one changes the alarm threshold and the other

cycles the LCD display mode.

## 3.2. Design Specification

The system operates as a periodic sensing-and-response loop. The STM32 acquires analog gas

data from the MQ2 sensor through its 12-bit ADC and reads temperature/humidity values from

the DHT11 using a timing-based single-wire routine. The firmware then updates the alarm

state, refreshes the LCD according to the selected display mode, and transmits environmental

values through the wireless UART interface. Unlike the earlier draft, the final implementation

does not use a snooze function or Bluetooth enable/disable mode. Instead, BUTTON_1 changes

the gas threshold between 660 ppm and 10 ppm for demonstration, while BUTTON_2 cycles

the LCD through four fixed display screens.

## 3.3. Hardware Specification

Subsystem | Component | Main Function | Operat ing Voltage | Interface / Connection | Notes
Processing Unit | STM32F103C 8T6 microcontrolle r | Central control, sensor reading, logic execution, display update, and wireless transmission | 3.3 V | ADC, GPIO, I2C, UART, Timer | Main controller of the system

Temperature and Humidity Sensing | DHT11 | Measures ambient temperature and relative humidity | 3.3 V | 1-wire digital interface via GPIO | Low-cost sensor for indoor monitoring
Gas Sensing | MQ-2 module | Detects gas/smoke level and provides analog output | 5 V | Analog output to ADC input | Gas density value is approximate and used for demonstration and threshold warning
Local Display | 16x2 LCD with PCF8574 I2C backpack | Displays system status and measured values locally | 5 V | I2C bus | Reduces GPIO usage by using only SDA and SCL
Wireless Communicati on | HC-05 Bluetooth module | Sends environmenta l data wirelessly to smartphone or serial Bluetooth app | 5 V | UART | Used for remote monitoring
Audible Alert | Active buzzer with transistor driver | Generates alarm sound when gas threshold is exceeded | 5 V | GPIO output through transistor driver | Driver circuit protects the MCU from high current load
User Input | Push button 1 | Changes gas alarm threshold between 660 ppm and 10 ppm | 3.3 V logic | GPIO input | Used for demonstration of alarm behavior
User Input | Push button 2 | Cycles the LCD display through 4 modes | 3.3 V logic | GPIO input | Used for local interface control
Visual Status Indicator | LED | Heartbeat indicator showing the firmware is running | 3.3 V logic | GPIO output | Toggles periodically during operation
5 V Regulation | LM2596 buck converter | Converts 9 V input to regulated 5 V rail | 9 V input / 5 V output | Power stage | Supplies MQ-2, LCD, Bluetooth module, and buzzer
3.3 V Regulation | AMS1117-3.3 regulator | Converts 5 V rail to regulated 3.3 V rail | 5 V input / 3.3 V output | Power stage | Supplies MCU and DHT11

Debug
Interface

USB-to-TTL
serial interface

Displays
debug
messages
during
development
and testing

3.3 V
logic
UART
UART | Used during firmware testing and debugging

The hardware specification of the final prototype includes the STM32 controller board, MQ2

analog gas sensor, DHT11 temperature-humidity sensor, 16x2 LCD with I2C backpack, active

buzzer with transistor driver, HC-05 wireless UART module, two push buttons, and a two-

stage power supply based on LM2596 and AMS1117. The hardware is designed to support

ADC, I2C, UART, GPIO, and timer-based signal timing in a compact desktop monitoring

platform.

## 3.4. Software Specification

The software is implemented using STM32 HAL and organized into an APP layer and a BSP

layer. The BSP layer contains hardware-specific modules for LED, buzzer, buttons, gas

sensing, DHT11, LCD, debug UART, and Bluetooth UART. The APP layer performs periodic

sensing, threshold evaluation, LCD mode control, heartbeat LED operation, and wireless

message formatting. This modular structure improves code readability, debugging, and

subsystem reuse.

At startup, APP_Init configures the high-level system behavior by initializing the LCD,

launching the timer used for DHT11 timing support, and preparing the status outputs. During

runtime, APP_Run periodically updates the DHT11 reading, toggles the heartbeat LED,

handles button events, refreshes the LCD according to the selected mode, updates the gas

threshold alarm logic, and sends formatted environmental messages through the Bluetooth

UART channel.

## 3.5. Test Specification

The system shall be tested in three stages: logic verification in Proteus, functional verification

on breadboard hardware, and board-level validation on the fabricated PCB. Simulation is used

mainly for digital logic and flow verification, while final confidence is obtained from real

hardware tests, especially for LCD operation, UART communication, Bluetooth transmission,

and threshold-based alarm response.

## 4. System partitioning and Architecture

## 4.1. System Partitioning

The Mini Environmental Monitoring Station is structured into five distinct functional

subsystems to ensure high modularity and efficient firmware development. The Sensing

Subsystem utilizes DHT11 and MQ2 sensors to capture ambient temperature, humidity, and

gas data. These signals are directed to the Processing Subsystem, centered on the

STM32F103C8T6 microcontroller, which is responsible for logic execution and threshold

evaluation. Local interaction is managed by the User Interface Subsystem, featuring a 16x2

I2C LCD, an active buzzer for gas-threshold alerts, and buttons for threshold selection and

display mode cycling. The Communication Subsystem utilizes a HC-05 Bluetooth UART

module for wireless connectivity. Crucially, the firmware manages two separate UART

channels: one dedicated to real-time debug messages and another for continuous environmental

data transmission to a mobile application. Finally, the Power Subsystem provides a regulated

energy backbone, converting the external 9V input into 5V and 3.3V rails to meet all hardware

voltage requirements.

## 4.2. Overall block diagram

As illustrated in Figure 4.2, the overall system architecture is organized around the

STM32F103C8T6 microcontroller, which serves as the central hub for data processing and

subsystem coordination. The Power Supplier block manages the energy distribution, beginning

with a 9V DC Adapter input that is regulated down to a 5V Rail via an LM2596 buck converter.

This 5V supply is then further stepped down by an AMS1117 regulator to provide a stable 3.3V

Rail for the MCU and sensors. This tiered power distribution ensures energy stability and

provides a common ground for all functional modules.

The input layer integrates both environmental sensors and manual user controls. Specifically,

the DHT-11 module provides digital humidity and temperature data via a GPIO interface, while

the MQ2 module monitors gas and smoke levels using an Analog-to-Digital Converter (ADC).

User interaction is facilitated through a dedicated button block, featuring a Threshold button

and an LCD mode button—both connected via GPIO inputs to manage alarm threshold

selection and display states.

For output and communication, the design incorporates a multi-interface strategy to provide

comprehensive feedback. Local data visualization is achieved using an LCD Screen connected

through an I2C bus to minimize pin usage. Remote reporting is established via a HC-05 module

using a UART interface to transmit formatted environmental packets to a mobile application.

Additionally, an audible alert system is implemented using a Buzzer driven by a dedicated

Buzzer Driver circuit connected to a GPIO pin, ensuring immediate notification when

environmental safety thresholds are exceeded.


Figure 4.2.1: System Block Diagram


Figure 4.2.2: System Block Diagram

## 4.3. Data flow

The system data flow begins at the sensing layer, where the DHT11 provides temperature and

humidity data and the MQ2 provides an analog gas-related voltage. The STM32 reads these

inputs, converts them into software variables, and then executes three parallel output tasks:

updating the LCD, controlling the buzzer according to the gas threshold, and transmitting

environmental data through the HC-05 module. The control flow remains in the main firmware

loop, while button actions are checked regularly to change the threshold or the LCD display

mode. Unlike the earlier draft, the final implemented logic does not include a snooze alarm or

Bluetooth transmission enable/disable mode.

## 4.4. Pin and interface allocation

MCU Pin / Peripheral | Peripheral | Interface Type | Description
PA0 | MQ2 Sensor | Analog (ADC1_IN0) | Performs gas analog acquisition to estimate density.

MCU Pin / Peripheral | Peripheral | Interface Type | Description
PA1 | DHT11 Sensor | Digital (GPIO) | Uses timer-based 1-wire routine for temperature and humidity reading.
PB6 | LCD I2C | I2C1 (SCL) | Serial clock line for the 16x2 local display interface.
PB7 | LCD I2C | I2C1 (SDA) | Serial data line for the 16x2 local display interface.
PB0 | Buzzer Driver | Digital Output | Controls the active buzzer for threshold-based gas warnings.
PB12 | Button 1 | Digital Input | User interface button for gas alarm threshold selection (660/10 ppm).
PB13 | Button 2 | Digital Input | User interface button for cycling through the 4 LCD display modes.
UART (Debug) | Serial Terminal | UART | Dedicated channel for firmware development and real-time debugging.
UART (Wireless) | HC-05 Bluetooth | UART | Transmits separate messages for environmental values to mobile app.
TIM2 | Internal Timer | Hardware Timer | Provides microsecond delay support for DHT11 signal timing.

## 5. Hardware Design

## 5.1. Design considerations

The design of the Mini Environmental Monitoring Station balances technical performance,

affordability, and practical implementation for an academic embedded system project. To

ensure the project objectives are met within the specified constraints, the selection of hardware

components is guided by several critical criteria. The primary consideration is the availability

of adequate hardware interfaces, specifically the requirement for integrated I2C, UART, ADC,

and multiple GPIO channels to support simultaneous communication with various sensors and

peripherals. Furthermore, the components must be easily accessible in the local market and

cost-effective, adhering to a total budget limit of 250,000 VND. The hardware is also selected

to be appropriate for the junior-level academic scope, offering a professional-grade platform

that is nonetheless easy to simulate in software like Proteus and straightforward to prototype

on a breadboard.

Beyond component selection, the hardware architecture incorporates fundamental embedded

system design factors including cost, power, size, and reliability. Cost management is achieved

by utilizing standardized modules such as the DHT11 and MQ2, which provide reliable

environmental data at a low entry price. For power efficiency, the system utilizes an LM2596

buck converter to regulate the 9V adapter input to a stable 5V rail, minimizing thermal

dissipation compared to standard linear regulators. The design is intentionally compact to

facilitate desktop use, ensuring the final assembled device fits within the specified volume of

20 cm x 10 cm x 10 cm. To ensure operational reliability, the hardware is designed to support

continuous 24-hour operation and includes considerations for software-based fault recovery

mechanisms, such as a watchdog timer, to prevent system failure during long-term monitoring.

These considerations ensure that the current design provides a robust and realistic solution for

indoor air quality monitoring.

The next section will detail the specific selection and justification of the STM32F103C8T6

Microcontroller as the central processing unit for this architecture.

## 5.2. Microcontroller selection


Figure 5.2: Microcontroller STM32F103C8T6

The STM32F103C8T6 microcontroller serves as the central processing unit and architectural

hub for the Mini Environmental Monitoring Station. Tasked with executing the system’s core

logic, this 32-bit MCU manages real-time data acquisition from sensors, evaluates safety

thresholds, and coordinates the output peripherals to ensure reliable user feedback. The

selection of this specific platform was driven by its ARM Cortex-M3 architecture, which

provides the necessary computational headroom for concurrent tasks—such as high-speed

ADC sampling for the MQ2 sensor and I2C communication for the LCD—without

performance bottlenecks. This processing capability directly supports the hardware

configuration previously detailed, enabling the simultaneous management of the dual UART

channels for debugging and HC-05 wireless transmission while maintaining stable timing for

the DHT11 sensor.

Beyond raw performance, the microcontroller’s rich set of integrated peripherals aligns

perfectly with the project’s hardware requirements. The availability of dedicated I2C, UART,

and 12-bit ADC channels allows for a streamlined hardware design, minimizing the need for

external interface components and reducing the overall PCB footprint. This high level of

integration is essential for maintaining the device's compact desktop form factor while ensuring

precision in environmental monitoring. Furthermore, the choice is highly cost-effective,

directly supporting the project's strict budget constraint of less than 250,000 VND. Its

suitability for the academic scope of the project, combined with its compatibility with

simulation tools and breadboard-friendly layout, made it the ideal choice for iterative

development and verification.

The resource allocation for this design utilizes the MCU's capabilities efficiently, ensuring

zero-conflict operation between various functional subsystems. Specifically, pin PA0 is

assigned to the MQ2 sensor's analog input, while PA1 handles the digital 1-wire protocol for

the DHT11 sensor. Communication with the 16x2 LCD is managed via pins PB6 and PB7 using

the I2C1 bus. The HC-05 Bluetooth module interfaces through a dedicated UART channel,

allowing the system to transmit formatted environmental messages to the mobile application

while maintaining a separate UART channel for real-time debugging. Additionally, the MCU’s

External Interrupt (EXTI) capabilities are leveraged on pins PB12 and PB13 to provide

instantaneous responsiveness for the display mode. This configuration ensures that user inputs

are processed with high priority, allowing for seamless interaction even during intensive sensor

sampling cycles.

## 5.3. Power supply design


Figure 5.3.1: Power supple modules LM2596 and AMS1117

The power system is designed as a tiered distribution architecture to ensure voltage stability

and energy efficiency for the entire monitoring station , as detailed in the Power Distribution

Tree (Figure 5.1) and the Power Supply Schematic (Figure 5.2). The primary power source

originates from a 9V DC Adapter (2A, 18W maximum power), which is subsequently regulated

through two distinct step-down stages to meet the specific voltage requirements of each

component.The first regulation stage utilizes an LM2596 buck converter to transform the 9V

input into a 5V Rail.

As shown in the schematic in Figure 5.2 , this block features a 100uH inductor, an MSS1P4

diode, and a 330uF filtering capacitor system to optimize efficiency and minimize ripple

voltage. The 5V Rail serves as the primary backbone, supplying power to high-power modules.

Specifically, the power tree in Figure 5.1 shows that this rail powers the MQ-2 gas sensor

(250mA peak), the HC-05 Bluetooth module (80mA peak), the 16x2 LCD with I2C interface

(90mA peak), and the active buzzer (100mA peak).To provide a stable and low-noise supply

for the logic processing unit, a second regulation stage is implemented using an AMS1117

linear regulator to convert 5V to a 3.3V Rail.

The schematic in Figure 5.2 illustrates that the 3.3V output is equipped with parallel filtering

capacitors (4.7uF, 22uF, 1uF, and 100uF) to ensure signal purity. This rail is dedicated to the

STM32F103C8T6 Bluepill microcontroller (35mA average) and the DHT11 sensor (~1mA

average). This tiered distribution effectively isolates electrical noise generated by power-

hungry modules like the MQ-2 and Buzzer, preventing voltage brownouts in the central

processing block.The design's reliability is confirmed through the Thermal Check tables

integrated into Figure 5.1. For the LM2596, at an average load of 0.30A, the junction

temperature (Tj) is calculated to be only 26-33°C (with an ambient temperature Ta = 25°C),

which is well within the ideal operating range. Even when operating at a peak current of 0.60A,

the Tj remains stable at 46-55°C. For the AMS1117, at a rated current of 80mA, the Tj reaches

approximately 32-39°C. These parameters demonstrate that the system not only operates

efficiently but also ensures absolute thermal safety, allowing the device to function

continuously for at least 24 hours without the risk of overheating or voltage instability.


Figure 5.3.2: Power Distribution Tree (Full schematic page)


Figure 5.3.3: Power Distribution Tree (Zoom in)


Figure 5.3.4 : Power Supply Schematic (Full schematic page)


Figure 5.3.4 : Power Supply Schematic (Zoom in)

## 5.4. Sensor interface design

The sensor interface design focuses on establishing reliable data acquisition from the physical

environment using both digital and analog protocols. This layer ensures that ambient variables

are accurately captured and converted into a format suitable for the STM32 processing core.

## 5.4.1. DHT11 interface

Figure 5.4.1 : DHT-11 Sensor

The DHT11 sensor is utilized to monitor indoor temperature and relative humidity. It employs

a proprietary 1-wire digital protocol, where a 40-bit data packet is transmitted to the MCU

through a single GPIO pin, PA1. The interface requires precise timing to distinguish between

high and low bits representing the environmental data. To ensure signal stability, the data line

is typically pulled high via a resistor, allowing the sensor to drive the line low to initiate

communication. This configuration provides humidity readings in %RH and temperature in

degrees Celsius (°C).

## 5.4.2. MQ2 analog interface


Figure 5.4.2 : MQ-2 Sensor

The MQ2 module is integrated to detect the presence of combustible gases and smoke. Unlike

the digital DHT11, the MQ2 provides a continuous analog voltage level proportional to the gas

concentration in the air. This signal is routed to the STM32 pin PA0, which is configured as an

Analog-to-Digital Converter (ADC1_IN0) input. The MCU utilizes its internal 12-bit ADC to

sample this voltage, subsequently applying mathematical mapping to determine the gas density

in parts per million (ppm). This interface is critical for the safety subsystem, as it provides the

raw data needed to evaluate against the 800 ppm alarm threshold.

## 5.5. User interface and communication circuits

## 5.5.1. LCD I2C interface


Figure 5.5.1 : LCD Screen with I2C backpack PCF8574

Local data visualization is achieved through a 16x2 LCD screen. To minimize the number of

required GPIO pins, the display is connected via an I2C backpack based on the PCF8574

remote 8-bit I/O expander. The interface uses only two serial lines: SCL connected to PB6 and

SDA connected to PB7. This configuration allows the STM32 to transmit formatted character

strings, such as "Temp:XX.X*C" and "Humidity:XX.X%RH", to the screen for immediate

display.

## 5.5.2. Button interface


Figure 5.5.2 : Buttons and their drivers

The system uses two push buttons. BUTTON_1 is connected to PB12 and is used to change

the gas alarm threshold between 660 ppm and 10 ppm. BUTTON_2 is connected to PB13 and

is used to cycle the LCD through four display modes. This design provides a simple and

effective demonstration interface without increasing hardware complexity.

## 5.5.3. Buzzer driver


Figure 5.5.3 : Buzzer and its drivers

The audible alert system uses an active buzzer to notify users of hazardous conditions. Since

the buzzer requires more current than a standard MCU GPIO can safely provide, a dedicated

buzzer driver circuit is implemented. This circuit uses a transistor to act as an electronic switch,

controlled by pin PB0. When the firmware detects a threshold violation (> 660 ppm), it sets

PB0 high to saturate the transistor and activate the alarm.

## 5.5.4. HC-05 UART interface

Figure 5.5.4 : Bluetooth module

Remote monitoring is established via an HC-05 Bluetooth module using a UART interface.

The module's TX and RX pins are cross-connected to the MCU's PA3 (RX) and PA2 (TX) pins

respectively. The system transmits formatted data frames containing temperature, humidity,

and gas density values at a standard baud rate to a paired mobile application. This interface

enables the "Mini Environmental Monitoring Station" to serve as a IoT-ready device for remote

surveillance.

## 5.6. Complete schematic design

The overall system schematic is presented in Figure 5.3, illustrating all electrical and logic

connections between the central microcontroller and the peripheral modules. The design is

organized into distinct functional blocks to ensure transparency, providing optimal support for

the system testing and maintenance processes.

At the heart of the circuit is the STM32F103C8T6 microcontroller, equipped with essential

support circuits for stable operation. This block includes external crystal oscillators (HSE

8MHz and LSE 32.768kHz), a hardware reset circuit integrated with pushbutton SW1, and

decoupling capacitors (C18, C19, C20) positioned near the MCU power pins. The BOOT0 pin

is configured via a resistor to determine the system's boot mode.

The sensor and input block is designed to collect environmental data accurately. The DHT11

sensor connects to pin PA1 through a pull-up resistor R12 to maintain signal integrity for digital

1-wire communication. The MQ2 sensor connects to analog pin PA0 using a voltage divider

circuit with load resistor R10 to convert gas concentration into a voltage signal compatible with

the MCU's 12-bit ADC. Additionally, two interactive buttons are equipped with pull-up

resistors R8 and R9: BUTTON 1 is dedicated to gas alarm threshold selection, and BUTTON

2 is used to cycle through LCD display modes.

Display and communication interfaces are integrated through standard buses to optimize

hardware resources. The LCD screen uses an I2C converter module (PCF8574) connected to

pins PB6 and PB7, accompanied by pull-up resistors R2 and R3 to ensure data transmission

stability. The wireless communication block employs a HC-05 Bluetooth module connected

via a dedicated UART channel, enabling the continuous transmission of formatted

environmental data frames to the mobile application.

The audible alarm system utilizes a buzzer controlled by an NPN transistor (Q1) through

current-limiting resistor R6. This circuit is protected by diode D3 to suppress flyback pulses

generated during buzzer switching. Finally, the design integrates a status LED (DS1) and a

UART_DEBUG header, which was retained for development and verification, facilitating real-

time monitoring and direct hardware debugging during the system integration phase.


Figure 5.6.1: Overall System Schematic (Full schematic page)


Figure 5.6.2: Overall System Schematic (Zoom in)

## 5.7. PCB layout design


Figure 5.7.1: 2D PCB Layout

## 5.8. Prototype and fabricated hardware


Figure 5.7.2: 3D PCB Render

Figure 5.8.1: Fabricated PCB - Top Side

Figure 5.8.2: Fabricated PCB - Bottom Side

## 6. Firmware Design

## 6.1. Firmware architecture


Figure 6.1: Firmware structure

The final firmware is structured into two layers: a Board Support Package (BSP) layer and an

Application (APP) layer. The BSP layer contains low-level functions for each hardware block,

such as LED, buzzer, buttons, gas sensor, LCD, DHT11, debug UART, and wireless UART.

The APP layer combines these modules into the final system behavior, including threshold

switching, display mode management, heartbeat signaling, sensor reading, alarm control, and

wireless transmission. This organization reduces coupling between hardware details and

system logic, making the code easier to maintain and extend.

## 6.2. Peripheral configuration

The firmware configures the ADC for MQ2 gas acquisition, I2C for LCD communication,

timer-based microsecond delay support for DHT11 communication, one UART for debug

messages, and one UART for the HC-05 wireless module. GPIO lines are used for the buzzer

driver, two push buttons, the heartbeat LED, and the DHT11 data line. The code is generated and managed in STM32CubeIDE using the HAL framework, with application-specific logic

implemented on top of the generated initialization code.

## 6.3. Main firmware workflow

After initialization, the firmware enters an infinite loop. The loop periodically attempts to read

the DHT11 sensor, toggles the heartbeat LED, checks button events, updates the gas alarm

logic, refreshes the LCD display, and sends environmental messages through the wireless

UART. BUTTON_1 changes the gas threshold between 660 ppm and 10 ppm, while

BUTTON_2 cycles the LCD mode. The gas sensing routine continuously updates the

approximate gas density value, compares it against the current threshold, and activates or

deactivates the buzzer accordingly.

## 6.4. Sensor acquisition logic

The sensor acquisition layer serves as the primary data source for the system, responsible for

converting physical environmental changes into digital values that the STM32F103C8T6 can

process. This logic is partitioned into two distinct routines based on the specific communication

protocols required by the integrated hardware components. The system architecture ensures a

closed-loop process where raw signals from the sensing layer are captured and mathematically

converted into standardized units of measure, such as degrees Celsius, percentage relative

humidity, and parts per million.

## 6.4.1. DHT11 read sequence

The acquisition logic for the DHT11 follows a strict timing sequence required by its proprietary

1-wire protocol. To initiate communication, the MCU sends a start signal by pulling the PA1

pin low for at least 18ms and then releasing it to high. Following this, the MCU switches the

pin to input mode and waits for the DHT11 to provide a response signal, indicating it is ready

to transmit data. The sensor then transmits a 40-bit packet consisting of 16 bits for humidity,

16 bits for temperature, and an 8-bit checksum used for data integrity verification. If the timing

between received bits exceeds the expected duration or if the checksum does not match the

data, the firmware implements fail-handling procedures by discarding the reading and

maintaining the last valid value.

In simulation, the DHT11 model showed some instability, so the final confidence in the

implementation was obtained through real hardware behavior and code integration rather than

simulation alone.

## 6.4.2. MQ2 ADC sampling

The MQ2 sensor logic relies on the STM32’s internal Analog-to-Digital Converter (ADC) to

interpret ambient gas and smoke concentrations. The firmware initiates a conversion on the

ADC1_IN0 channel connected to pin PA0, allowing the MCU to capture a 12-bit raw digital

value representing the analog voltage levels from the sensor. This raw value is compared

against a calibrated digital threshold that corresponds to the 800 ppm safety limit.The MQ2

sensor is connected to the MCU through an ADC channel. The firmware reads the analog

voltage, performs software scaling, and generates an approximate gas density value for

demonstration and threshold-based warning. This value is sufficient for comparing relative gas

levels and for triggering the alarm logic in the final prototype.

## 6.5. Alarm and display logic

The final prototype activates the buzzer when the gas density value exceeds the currently

selected threshold. BUTTON_1 allows the demonstrator to switch between a high threshold of

660 ppm and a very low threshold of 10 ppm, making it easy to show both normal and alarm

states during presentation. BUTTON_2 cycles the LCD through four modes: a welcome screen,

gas density, temperature, and humidity. In addition, a heartbeat LED toggles periodically to

show that the firmware is alive even when no button is pressed.

## 6.6. Bluetooth transmission logic

The wireless subsystem sends environmental information through the HC-05 module. Instead

of packaging all values into one long sentence, the final firmware transmits three separate fixed-

format lines: one line for temperature, one line for humidity, and one line for gas density. A

separator line is transmitted after each update group to improve readability on the mobile serial

Bluetooth terminal.

## 6.7. Error handling and robustness

The firmware is designed so that a sensor read failure does not stop the whole system. If the

DHT11 read routine fails, an error message is printed to the debug UART, while the remaining

functions—LCD mode handling, buzzer control, gas sensing, and wireless transmission—

continue to operate. This simple fault containment strategy increases the robustness of the final

prototype without adding excessive software complexity.

## 7. Integration and Testing

## 7.1. Integration strategy


Figure 7.1: Full system integration on breadboard

The integration process was carried out incrementally. The team first verified basic GPIO and

UART communication, then validated the buzzer and button behavior, followed by ADC-based

gas sensing. LCD I2C communication was then confirmed on real breadboard hardware.

Finally, the wireless transmission channel and the complete APP–BSP integrated firmware

were validated. This staged approach reduced debugging complexity and made it easier to

isolate subsystem errors before the final full-system test.

## 7.2. Simulation results


Figure 7.2.1: The simulation module in Proteus

Proteus simulation was primarily used to verify logic flow, GPIO control, ADC scaling

behavior, buzzer control, and UART message formatting. Some simulated peripheral models,

especially DHT11 and LCD I2C, were less reliable than the corresponding real hardware.

Therefore, simulation was used mainly as an intermediate verification step rather than the sole

source of final validation.

Figure 7.2.2: Successful simulation result with buzzer on and HC-05 sending messages

## 7.3. Breadboard test results


Figure 7.3.1: LCD in displaying gas density mode

Figure 7.3.2: LCD in displaying temperature mode


Figure 7.3.3: LCD in displaying humidity mode

Figure 7.3.4: Phone app successfully received messages from bluetooth module HC-05


Figure 7.3.5: Hercules successfully received messages from USB to TTL module

Breadboard testing confirmed the final behavior of the prototype on real hardware. The LCD

successfully displayed all four modes. The gas value changed according to sensor output and

triggered the buzzer according to the selected threshold. BUTTON_1 correctly changed the gas

threshold between 660 ppm and 10 ppm, while BUTTON_2 correctly cycled the LCD display

modes. Temperature and humidity values were shown locally and also transmitted wirelessly

through the HC-05 module to a smartphone serial Bluetooth application.


Figure 7.3.6: Read gas density in normal condition

Figure 7.3.7: Read gas density in smoke environment

For the gas sensor test, we burnt an incense stick to generate smoke and put it near the MQ-2

sensor. As observed, the read gas density gradually increased over time until reached 660 ppm,

the buzzer was activated. After the incense stick was put away, this number decreased back to

its normal condition value and the buzzer was turned off.


Figure 7.3.8: Read temperature in normal condition

Figure 7.3.9: Read temperature when being near soldering iron

In the temperature test, we use a soldering iron to make heat and put its head next to DHT-11

sensor, the room temperature before the test was 27 Celcius degree, after a period of time, it

rocketed to approximately 62 Celcius degree. This shows that the DHT-11 sensor is sensitive

to the alternation of temperature.

## 7.4. PCB bring-up and validation

The PCB was fabricated successfully and basic power and continuity checks were performed.

During debugging and firmware refinement, however, the breadboard prototype remained the

main platform for subsystem validation because it allowed faster rewiring and easier

observation of signals. The PCB therefore demonstrates the manufacturability of the design,

while | the | breadboard | demonstrates | the | final | validated | functional | behavior.

## 7.5. Requirement verification matrix

Requirement ID | Verification Method | Result
FR-1.1.1: Temperature sensing | Observed on 16x2 LCD (Mode 3) and verified via HC-05 Bluetooth terminal output in °C. | Passed
FR-1.1.2: Humidity sensing | Observed on 16x2 LCD (Mode 4) and verified via HC-05 Bluetooth terminal output in %RH. | Passed
FR-1.1.3: Gas sensing | Monitored approximate ppm-like values on LCD (Mode 2) during exposure to gas sources. | Passed
FR-2.1.1: Threshold switching | Physical interaction with BUTTON_1 to toggle alarm threshold between 660 ppm and 10 ppm. | Passed
FR-2.1.2: LCD mode cycle | Physical interaction with BUTTON_2 to cycle through the four defined display screens. | Passed
FR-3.1: Buzzer alarm | Verified audible activation when gas density exceeded the selected threshold. | Passed

Requirement ID | Verification Method | Result
FR-4.1: Wireless transmission | Verified reception of three separate formatted messages on a mobile Bluetooth serial application. | Passed

## 7.6. Discussion of results

The final prototype successfully demonstrates the complete embedded workflow from sensing

to processing, local display, alarm generation, and wireless reporting. The BSP–APP software

structure improved maintainability and made hardware integration more systematic. The

strongest results were obtained on breadboard hardware, where LCD operation and wireless

data transmission were verified successfully. Some limitations remain: the gas value is an

approximate ppm-like scaled value rather than an industrially calibrated gas concentration, and

some Proteus peripheral models were not fully reliable. Nevertheless, the final prototype meets

the main educational and functional objectives of the project.

The test videos can be view in the following links:

Full test: https://youtu.be/GwvQwB3FSAY

Gas test: https://youtu.be/L1KeKjgLLEk

Temp test: https://youtu.be/eYzAX3KRrvM

## 8. Conclusion

This project successfully developed a mini environmental station based on the STM32 platform

for indoor monitoring applications. The final prototype integrates temperature-humidity

sensing, gas sensing, local LCD visualization, audible gas-threshold warning, and wireless data

transmission through a Bluetooth UART module. The implementation also demonstrates a

modular firmware structure based on BSP and APP separation, which simplified development

and debugging. Although some peripheral models in simulation were not fully stable and the

gas density value remains approximate rather than industrially calibrated, the real hardware

prototype achieved the intended functionality and provided a complete end-to-end embedded

system demonstration. Future work may include improved gas calibration, enclosure design,

cloud connectivity, and a more accurate environmental sensor set.

## 9. Reference

Advanced Monolithic Systems. (n.d.). AMS1117: 800mA low dropout voltage regulator [Datasheet].

Aosong (Guangzhou) Electronics Co., Ltd. (n.d.). DHT11 humidity & temperature sensor [Datasheet].

Hanwei Electronics Co., Ltd. (n.d.). Technical data: MQ-2 gas sensor [Datasheet].

HC-05 Bluetooth Module Technical Manual. (n.d.). HC-05 Bluetooth 3.0 serial port transparent transmission module

NXP Semiconductors. (2015). PCF8574; PCF8574A remote 8-bit I/O expander for I2C-bus [Datasheet].

STMicroelectronics. (n.d.). STM32F103x4, STM32F103x6: Medium-density performance line ARM-based 32-bit MCU with 16 or 32 KB flash [Datasheet].

STMicroelectronics. (2020). UM1850 user manual: Description of STM32F1 HAL and low-layer drivers.

STMicroelectronics. (2023). STM32CubeIDE user guide: Integrated development environment for STM32.

Texas Instruments. (2016). LM2596 SIMPLE SWITCHER® 150-kHz 3-A step-down voltage regulator [Datasheet].

## - The end -

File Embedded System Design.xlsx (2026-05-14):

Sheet: Project Overall
Mini environmental monitoring station with module LCD display using I2C module and can alert with buzzer when certain conditions are met, sent data measured to phone UART app via Bluetooth with UART communication (module HC-05). The station use mcu stm32f103c8t6 aka blue pill that can measure real-time temperature & humidity (module DHT11), gas (module MQ2), and can display them on the lcd screen. The device also has 2 button, 1 to snooze the alarm, 1 to change the display mode in cycle.

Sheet: Tasks management
Nhiệm vụ | Yêu cầu | Ngày giao việc | Hạn chót | Người phụ trách | Tình trạng | Đạt yêu cầu? | Ghi chú | Cột 8
Chốt đề tài Environment Station | Biểu diễn tổng quan các chức năng, nguyên lý hoạt động | 2026-01-16 | 2026-01-16 | Vinh, Ân, Dũng | Đúng hạn | TRUE | Bước đầu thành công, xuất phát sớm | Giai đoạn 1 - 0%
Viết Functional & Non-Functional requirement | Trình bày được đặc tả hệ thống Functional và Non-Functional rõ ràng, đầy đủ như mong muốn ban đầu, đúng lý thuyết Thầy Bảo dạy | 2026-01-17 | 2026-01-17 | Dũng | Đúng hạn | FALSE | Các mô tả chưa có tính cụ thể, một số chưa đúng với mô tả hệ thống ban đầu đã thống nhất. Cần chỉnh sửa lại, đánh giá cao sự đúng hạn
Chỉnh sửa Functional & Non-Functional requirement | Chỉnh lại FRs và NFRs với đúng kỳ vọng ban đầu và đúng chuẩn được dạy ở lớp | 2026-01-17 | 2026-01-17 | Vinh, Ân | Đúng hạn | TRUE
Viết System specification | Mô tả các component sử dụng để chạy hệ thống, cách kết nối, mode sử dụng của các modules | 2026-01-17 | 2026-01-19 | Vinh | Đúng hạn | TRUE
Họp và đánh giá lại 2 bước trên, góp ý chỉnh sửa | Chốt đề tài và làm rõ một số ý chưa thống nhất | 2026-01-21 | 2026-01-21 | Vinh, Ân, Dũng | Đúng hạn | TRUE | Đưa vào thêm một số chức năng mới, hiển thị lcd, đo nồng độ khí ga, gửi uart
Chỉnh lại Requirement và Specification | Sửa lại theo mô tả hệ thống đã thống nhất | 2026-01-21 | 2026-01-22 | Vinh | Đúng hạn | TRUE
Tìm hiểu DHT11 MQ2 LCD-I2C | Tìm hiểu cách hoạt động và hướng dẫn cho Vinh cách sử dụng | 2026-03-02 | 2026-03-04 | Dũng | Đúng hạn | FALSE | Đánh giá cao sự đúng hạn nhưng còn sơ sài, chatgpt . Vinh phải tự tìm hiểu sau đó
Vẽ schematic - Block diagram | Vẽ block diagram theo chuẩn được dạy | 2026-03-08 | 2026-03-15 | Vinh | Đúng hạn | TRUE
Vẽ schematic - Power tree | Vẽ power tree theo chuẩn, ghi rõ công suất và cường độ dòng từng linh kiện tiêu thụ | 2026-03-08 | 2026-03-15 | Vinh | Đúng hạn | TRUE
Vẽ schematic - Thermal check table | Thêm bảng đo nhiệt độ khi hoạt động, tạo sự nổi bật | 2026-03-08 | 2026-03-15 | Ân | Đúng hạn | TRUE |  | Giai đoạn 2 - 50%
Vẽ schematic - Power supply | Thiết kế bộ nguồn gồm LM2596, AMS1117 và các linh kiện vệ tinh để cấp power rail cho mạch | 2026-03-15 | 2026-03-22 | Ân | Đúng hạn | TRUE | Đầy đủ các khối, các linh kiện vệ tinh chưa đúng, validate còn lỗi
Vẽ schematic - Main system | Thiết kế các khối xử lý trung tâm: MCU Bluepill, Button driver, Sensors, LCD I2C, 2 Uart, Buzzer,... và các trở, tụ, xung quanh | 2026-03-15 | 2026-03-22 | Vinh | Đúng hạn | TRUE | Đày đủ các khối chức năng, validate còn lỗi, một số linh kiện chưua có footprint, đợi feedback từ thầy'
Sửa lỗi Power tree | Sửa sau khi nghe feedback thầy Bảo và validate còn 20 lỗi | 2026-03-23 | 2026-03-26 | Ân | Đúng hạn | TRUE | Đã ổn, đúng với datasheet ban đầu
Sửa lỗi Main system | Sửa sau khi nghe feedback thầy Bảo và validate còn 40 lỗi | 2026-03-23 | 2026-03-26 | Vinh | Đúng hạn | TRUE | Hết lỗi, đã chỉnh lại theo feedbackl
Vẽ các component không có trên Altium, vẽ tay | HC-05, MQ-2, một số linh kiện không có trong thư viện, yêu cầu phải vẽ symbol và footprint manually | 2026-03-23 | 2026-03-26 | Vinh | Đúng hạn | TRUE | Gắn header và chỉnh lại mode I/O của các linh kiện
Vẽ PCB Layout | Schematic đã được hoàn thiện và sửa hết lỗi, vẽ layout | 2026-03-26 | 2026-03-26 | Ân | Đúng hạn | TRUE | Đánh giá cao sự hardcore làm trong 1 ngày
Tổng hợp, upload lên github | Up tất cả tài liệu tiến độ hiện tại lên github để Dũng làm report | 2026-03-27 | 2026-03-27 | Vinh | Đúng hạn | TRUE
Làm report 50% | Làm report theo yêu cầu của Thầy ghi rõ trong slide: The report must be written following the embedded system design process | 2026-03-27 | 2026-03-30 | Dũng | Đúng hạn | FALSE | Dũng làm ổn, khung sườn cover gần đủ nhưng vẫn còn thiếu vài bước theo quy trình TKHTN, lấy sai hình cho report
Vẽ proteus để simulate | Vẽ lại toàn bộ hệ thống trên proteus dựa trên schematic altium và simulate, đi dây lại để phù hợp với mô phỏng | 2026-04-01 | 2026-04-02 | Vinh | Đúng hạn | TRUE | Đã vẽ lại hoàn chỉnh, project simulate được
Code stm32cubeide | Code firmware cho toàn bộ hệ thống, debug cho từng khối một và build lên từ từ, vừa code vừa mô phỏng để đảm bảo behave đúng | 2026-04-02 | 2026-04-11 | Vinh | Đúng hạn | FALSE | Tất cả các linh kiện đã chạy đúng trừ LCD chưa giao tiếp I2C được dù đã thử các địa chỉ 0x20 x27 x3F x3E và sử dụng code dò địa chỉ, DHT11 đọc sai số do các bit cuối dọc bị lệch cần phải test trên breadboard
Sửa lại report 50% | Làm report theo yêu cầu của Thầy ghi rõ trong slide: The report must be written following the embedded system design process | 2026-03-30 | 2026-04-09 | Dũng | Đúng hạn | FALSE | Đã ổn hơn lần trước, thêm được 5 đoạn nội dung ở đầu mỗi phần,, vẫn còn lấy hình sai
In PCB | In 5 mạch |  | 2026-04-05 | Ân | Đúng hạn | TRUE | Ân ứng tiền 190k
Làm lại báo cáo công việc trên excel | Viết lại biên bản làm việc rõ ràng và phân nhiệm vụ mới | 2026-04-11 | 2026-04-12 | Vinh | Đúng hạn | TRUE |  | Giai đoạn 3 - 100%
Mua linh kiện điện tử | Mua tất cả linh kiện điện tử cần để lắp mạch breadboard: HC05, MQ2, DHT11, LCD PCF, Breadboard, LM2596, AMS1117, dây... | 2026-04-11 | 2026-04-12 | Vinh | Đúng hạn | TRUE | Tổng bill 296k, vinh ứng
Làm report 100% | Viết một bản report hoàn chỉnh "The report must be written following the embedded system design process", bao gồm quá trình trong các slide bài giảng từ đầu đến cuối. Trình bày kĩ và đầy đủ nội dung mà team đã làm từ đầu đến cuối, viết thêm các phần lý thuyết để nộp. | 2026-04-12 | Sáng 24/04/2026 | Dũng | Đúng hạn | TRUE | Các tài liệu: https://docs.google.com/document/d/1ozNgph806v6iIgOBkZLcseK3Fe_vgAtyg2jRV2a9toI/edit?usp=sharing | Guideline: https://docs.google.com/document/d/1vAiog7G-fEwVRg1F-I0hjbZN5FIbIZKtpWRS2lV4W_4/edit?usp=sharing
Làm slide | Làm slide để thuyết trình 50% | 2026-04-12 | 2026-04-20 | Ân | Đúng hạn | TRUE | Ổn nhưng cần bổ sung chỉnh sửa
Sửa slide | Chỉnh lại slide thuyết trình 50%, làm rõ một số điểm và lược bớt những nội dung không cần thiết. | 2026-04-20 | 2026-04-20 | Vinh | Đúng hạn | TRUE
Thuyết trình | Thuyết trình 50% | 2026-04-12 | 2026-04-20 | Vinh | Đúng hạn | TRUE
Lắp mạch breadboard | Lắp lại hệ thống lên breadboard, có thể giống với sơ đồ trong proteus hay altium, tùy thuộc vào điều kiện thực tế. Mục tiêu là để thỏa mãn các yêu cầu ban đầu của hệ thống | 2026-04-12 | 2026-04-27 | Vinh | Đúng hạn | TRUE | Debug thành công lỗi hiển thị lcd
Sửa report 100% | Chỉnh sửa lại report nếu cần | 2026-04-20 | 27/04 (extend10/05) | Vinh, Dũng | Đúng hạn | TRUE | kéo dài đến 10/05
Nạp code lên breadboard và debug lại | Debug trên mạch breadboard để sửa 2 lỗi: chưa hiển thị được LCD, và đọc DHT11 chưa chính xác | 2026-04-20 | 2026-04-26 | Vinh | Đúng hạn | TRUE
Hoàn thiện sản phẩm trên breadboard 100% | Lắp driver cho buzzer, gửi bluetooth qua điện thoại bằng jdy 31 | 2026-04-27 | 2026-05-09 | Vinh | Đúng hạn | TRUE | Xong
Update github | Update lại trên github tiến độ sau khi hoàn thành | 2026-04-27 | 2026-04-27 | Vinh | Đúng hạn | TRUE
Làm slide thuyết trình 100% |  | 2026-05-09 | 2026-05-11 | Vinh, Ân | Đúng hạn | TRUE
Thuyết trình 100% | Thuyết trình 100% | 2026-05-11 | 2026-05-11 | Vinh | Đúng hạn | TRUE
 |  |  |  |  | Đang làm | FALSE
 |  |  |  |  | Đang làm | FALSE
 |  |  |  |  | Đang làm | FALSE
 |  |  |  |  | Đang làm | FALSE
 |  |  |  |  | Đang làm | FALSE
 |  |  |  |  | Đang làm | FALSE
 |  |  |  |  | Đang làm | FALSE
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

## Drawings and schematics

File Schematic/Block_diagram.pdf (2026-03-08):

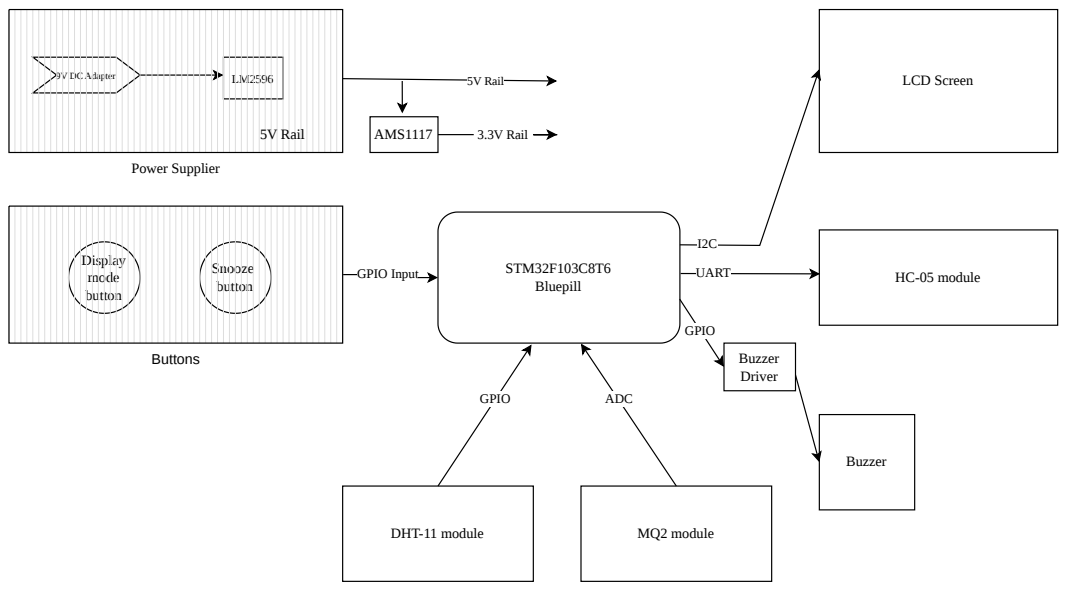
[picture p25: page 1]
STM32F103C8T6 Bluepill; 9V DC Adapter; LCD Screen; MQ2 module; HC-05 module; DHT-11 module; Buzzer; Snooze button; Display mode button; GPIO Input; Buttons; Power Supplier; 5V Rail; UART; GPIO; ADC; AMS1117; Buzzer Driver; 3.3V Rail

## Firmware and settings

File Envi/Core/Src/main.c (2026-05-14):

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
/* Includes ------------------------------------------------------------------*/
#include "main.h"
#include "adc.h"
#include "i2c.h"
#include "tim.h"
#include "usart.h"
#include "gpio.h"

/* USER CODE BEGIN Includes */
#include <stdio.h>
#include <string.h>
#include "bsp_led.h"
#include "bsp_buzzer.h"
#include "bsp_uart.h"
#include "bsp_gas.h"
#include "bsp_button.h"
#include "app.h"
/* USER CODE END Includes */


/* USER CODE BEGIN PV */
uint32_t gas_adc = 0;
uint8_t alarm_mute = 0;
uint8_t gas_alert = 0;
uint32_t gas_threshold = 2000;
/* USER CODE END PV */

void SystemClock_Config(void);
/**
  * @brief  The application entry point.
  * @retval int
  */
int main(void)
{

  /* MCU Configuration--------------------------------------------------------*/

  /* Reset of all peripherals, Initializes the Flash interface and the Systick. */
  HAL_Init();

  /* Configure the system clock */
  SystemClock_Config();

  /* Initialize all configured peripherals */
  MX_GPIO_Init();
  MX_ADC1_Init();
  MX_USART1_UART_Init();
  MX_USART2_UART_Init();
  MX_I2C1_Init();
  MX_TIM2_Init();
  /* USER CODE BEGIN 2 */
  APP_Init();
  /* USER CODE END 2 */

  /* Infinite loop */
  /* USER CODE BEGIN WHILE */
  while (1)
  {
	  APP_Run();
    /* USER CODE END WHILE */

    /* USER CODE BEGIN 3 */
  }
  /* USER CODE END 3 */
}

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


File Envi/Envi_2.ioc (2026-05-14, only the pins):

Mcu.UserName=STM32F103C6Tx
PA0-WKUP.Signal=ADCx_IN0
PA1.Signal=GPIO_Output
PA10.Signal=USART1_RX
PA13.Signal=SYS_JTMS-SWDIO
PA14.Signal=SYS_JTCK-SWCLK
PA2.Signal=USART2_TX
PA3.Signal=USART2_RX
PA8.Signal=GPIO_Output
PA9.Signal=USART1_TX
PB0.Signal=GPIO_Output
PB12.Signal=GPIO_Input
PB13.Signal=GPIO_Input
PB6.Signal=I2C1_SCL
PB7.Signal=I2C1_SDA

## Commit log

2026-02-28 Update README with project details and links
    Added project title, requirement definition, system specification, and placeholders for schematic and PCB layout.
2026-03-02 Update schematic and PCB layout status in README
2026-03-08 Add files via upload
    Schematic Altium
2026-03-08 Revise README with new diagrams and layout status
    Updated images and added power tree and schematic details.
2026-04-13 Update README to modify schematic and add PCB layout
    Removed multiple images from the schematic section and added a PCB layout section with images.

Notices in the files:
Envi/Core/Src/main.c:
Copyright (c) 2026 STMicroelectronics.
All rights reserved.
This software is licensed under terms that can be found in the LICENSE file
